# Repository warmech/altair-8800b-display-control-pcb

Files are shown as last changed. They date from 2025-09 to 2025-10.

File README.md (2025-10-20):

# Altair 8800B Display/Control PCB
This is a reproduction of the Altair 8800B Display/Control PCB, with some cleanup and reorganization of trace routing and pad placement. The 8800B’s D/C PCB, much like the original 8800’s front panel PCB, is the primary form of I/O for a stock machine: the LEDs for indicating the data/address/control signals and switches for setting the address and inputting data as well as controlling the CPU are to be found on this PCB. Unlike the original 8800, which drove the LEDs directly off the system bus, the 8800B D/C PCB buffers all signals and uses a 1702 EPROM (or just “PROM” as it would have originally been called) to pass control instructions off to the CPU.

This version of the D/C PCB is not a true 1:1 reproduction (just like the 8800B CPU and Interface cards), but strives to maintain a closely similar layout and trace routing to try to ensure that the hidden “feature” of the Altair remained present: the ability to generate EMI off the D/C board in such a fashion that music can be generated and received via an AM radio at very close proximity.

This design is presently untested and I am awaiting a set to be fabricated. Once I have tested this card in my 8800B, I will update this disclaimer to indicate as much. Until this disclaimer is updated and/or removed, this PCB is to be strictly treated as experimental only. User beware – these project and fabrication files are provided with absolutely zero guarantees.

For the accompanying CPU, Interface, and 1702-to-2716/32 adapter boards, please see the following repositories:

[Altair 8800B CPU Card](https://github.com/warmech/altair-8800b-cpu-card)

[Altair 8800B Interface Card](https://github.com/warmech/altair-8800b-interface-card)

[Altair 8800B 1702-to-2716/2732 Adapter](https://github.com/warmech/altair-8800b-1702-to-2716-eprom-adapter)

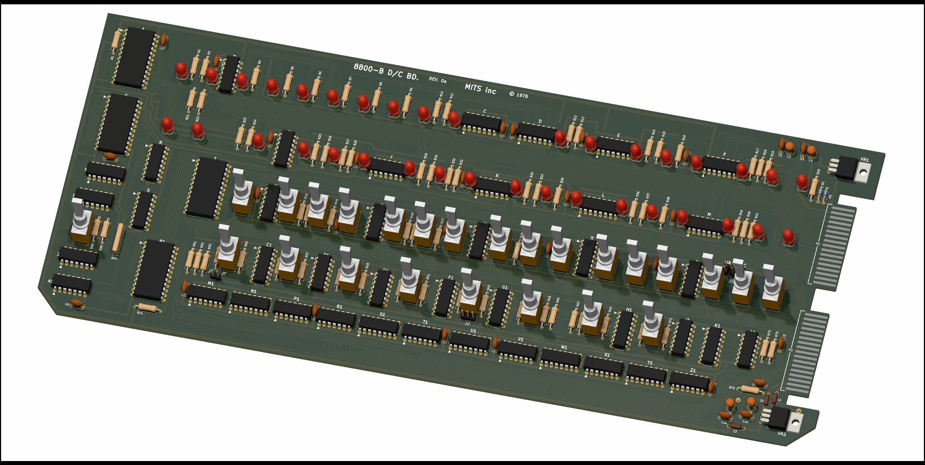
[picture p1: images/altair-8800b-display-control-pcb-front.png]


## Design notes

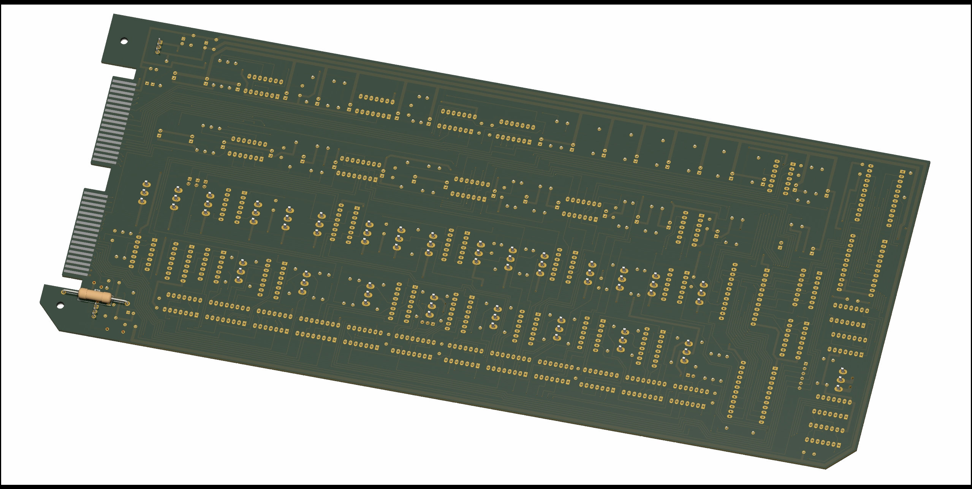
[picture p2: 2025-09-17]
images/altair-8800b-display-control-pcb-rear.png

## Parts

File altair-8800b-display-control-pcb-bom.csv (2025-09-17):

Source:
Date: | 9/16/2025 17:35
Tool: | Eeschema 7.0.11-rc3
Generator:
Component Count: | 232
Collated Components:
Item | Qty | Reference(s) | Value | LibPart | Footprint | Datasheet | DNP | Sim.Device | Sim.Pins
1 | 26 | C1, C3, C10, C11, C12, C13, C14, C15, C16, C17, C18, C19, C20, C21, C22, C23, C24, C25, C26, C27, C28, C29, C30, C31, C32, C33 | 0.1uF / 16V | Device:C | Capacitor_THT_Custom:C_Disc_D7.0mm_W2.3mm_P5.00mm | ~
2 | 4 | C2, C4, C8, C9 | 47uF / 16V | Device:C_Polarized_US | Capacitor_THT:CP_Radial_Tantal_D4.5mm_P2.50mm | ~
3 | 3 | C5, C6, C7 | 0.001uF | Device:C | Capacitor_THT_Custom:C_Disc_D7.0mm_W2.3mm_P5.00mm | ~
4 | 2 | D1, D2 | 1N914 | Diode:1N914 | Diode_THT:D_DO-35_SOD27_P7.62mm_Horizontal | http://www.vishay.com/docs/85622/1n914.pdf |  | D | 1=K 2=A
5 | 1 | J1 | JF_JE | Connector_Generic:Conn_01x02 | Connector_PinHeader_2.54mm:PinHeader_1x02_P2.54mm_Vertical | ~
6 | 1 | JP1 | JA | Jumper:Jumper_2_Open | Connector_PinHeader_2.54mm:PinHeader_1x02_P2.54mm_Vertical | ~
7 | 1 | JP2 | JB | Jumper:Jumper_2_Open | Connector_PinHeader_2.54mm:PinHeader_1x02_P2.54mm_Vertical | ~
8 | 1 | JP3 | JC | Jumper:Jumper_2_Open | Connector_PinHeader_2.54mm:PinHeader_1x02_P2.54mm_Vertical | ~
9 | 1 | JP4 | G_H_J | Jumper:Jumper_3_Bridged12 | Connector_PinHeader_2.54mm:PinHeader_1x03_P2.54mm_Vertical | ~
10 | 3 | L1, L2, L3 | L | Device:L | Inductor_THT:L_Axial_L5.3mm_D2.2mm_P7.62mm_Horizontal_Vishay_IM-1 | ~
11 | 36 | LED1, LED2, LED3, LED4, LED5, LED6, LED7, LED8, LED9, LED10, LED11, LED12, LED13, LED14, LED15, LED16, LED17, LED18, LED19, LED20, LED21, LED22, LED23, LED24, LED25, LED26, LED27, LED28, LED29, LED30, LED31, LED32, LED33, LED34, LED35, LED36 | LED | Device:LED | LED_THT:LED_D5.0mm | ~
12 | 1 | P1 | D/C Card Edge | :Ribbon_Cable_Card_Edge_Connector_34_Pin_1 | Connector_Custom:Altair_8800B_Display_Control_Card_Edge
13 | 1 | P2 | D/C Card Edge | Connector_Custom:Ribbon_Cable_Card_Edge_Connector_34_Pin | Connector_Custom:Altair_8800B_Display_Control_Card_Edge
14 | 34 | R1, R23, R27, R31, R42, R43, R44, R45, R46, R47, R48, R49, R51, R52, R53, R54, R55, R56, R57, R58, R59, R60, R61, R62, R63, R64, R65, R67, R68, R69, R70, R71, R72, R74 | 2.2K | Device:R_US | Resistor_THT:R_Axial_DIN0309_L9.0mm_D3.2mm_P12.70mm_Horizontal | ~
15 | 37 | R2, R3, R4, R5, R6, R7, R8, R9, R10, R11, R12, R13, R14, R15, R16, R17, R18, R19, R21, R22, R24, R25, R26, R28, R29, R30, R32, R33, R34, R35, R36, R37, R38, R39, R40, R41, R73 | 220 | Device:R_US | Resistor_THT:R_Axial_DIN0309_L9.0mm_D3.2mm_P12.70mm_Horizontal | ~
16 | 1 | R20 | 1K | Device:R_US | Resistor_THT:R_Axial_DIN0309_L9.0mm_D3.2mm_P12.70mm_Horizontal | ~
17 | 2 | R50, R75 | 100 | Device:R_US | Resistor_THT:R_Axial_DIN0309_L9.0mm_D3.2mm_P12.70mm_Horizontal | ~
18 | 1 | R66 | 470 | Device:R_US | Resistor_THT:R_Axial_DIN0309_L9.0mm_D3.2mm_P12.70mm_Horizontal | ~
19 | 1 | R76 | 5 Ohm / 4W | Device:R_US | Resistor_THT:R_Axial_DIN0516_L15.5mm_D5.0mm_P30.48mm_Horizontal | ~
20 | 1 | RP1 | 4.7K | Device:R_Network05_Split | Resistor_THT:R_Array_SIP6 | http://www.vishay.com/docs/31509/csc.pdf
21 | 1 | SW1 | A0 | Switch:SW_SPDT | Switch_Custom:Altair_Toggle_Switch | ~
22 | 1 | SW2 | A1 | Switch:SW_SPDT | Switch_Custom:Altair_Toggle_Switch | ~
23 | 1 | SW3 | A2 | Switch:SW_SPDT | Switch_Custom:Altair_Toggle_Switch | ~
24 | 1 | SW4 | A3 | Switch:SW_SPDT | Switch_Custom:Altair_Toggle_Switch | ~
25 | 1 | SW5 | A4 | Switch:SW_SPDT | Switch_Custom:Altair_Toggle_Switch | ~
26 | 1 | SW6 | A5 | Switch:SW_SPDT | Switch_Custom:Altair_Toggle_Switch | ~
27 | 1 | SW7 | A6 | Switch:SW_SPDT | Switch_Custom:Altair_Toggle_Switch | ~
28 | 1 | SW8 | A7 | Switch:SW_SPDT | Switch_Custom:Altair_Toggle_Switch | ~
29 | 1 | SW9 | A8 | Switch:SW_SPDT | Switch_Custom:Altair_Toggle_Switch | ~
30 | 1 | SW10 | A9 | Switch:SW_SPDT | Switch_Custom:Altair_Toggle_Switch | ~
31 | 1 | SW11 | A10 | Switch:SW_SPDT | Switch_Custom:Altair_Toggle_Switch | ~
32 | 1 | SW12 | A11 | Switch:SW_SPDT | Switch_Custom:Altair_Toggle_Switch | ~
33 | 1 | SW13 | A12 | Switch:SW_SPDT | Switch_Custom:Altair_Toggle_Switch | ~
34 | 2 | SW14, SW25 | A13 | Switch:SW_SPDT | Switch_Custom:Altair_Toggle_Switch | ~
35 | 1 | SW15 | A14 | Switch:SW_SPDT | Switch_Custom:Altair_Toggle_Switch | ~
36 | 1 | SW16 | A15 | Switch:SW_SPDT | Switch_Custom:Altair_Toggle_Switch | ~
37 | 1 | SW17 | STOP_RUN | Switch:SW_SPDT_MSM | Switch_Custom:Altair_Toggle_Switch_Momentary | ~
38 | 1 | SW18 | STEP_SLOW | Switch:SW_SPDT_MSM | Switch_Custom:Altair_Toggle_Switch_Momentary | ~
39 | 1 | SW19 | EXAMINE_NEXT | Switch:SW_SPDT_MSM | Switch_Custom:Altair_Toggle_Switch_Momentary | ~
40 | 1 | SW20 | DEPOSIT_NEXT | Switch:SW_SPDT_MSM | Switch_Custom:Altair_Toggle_Switch_Momentary | ~
41 | 1 | SW21 | ACC_DIS_DEP | Switch:SW_SPDT_MSM | Switch_Custom:Altair_Toggle_Switch_Momentary | ~
42 | 1 | SW22 | IN_OUT | Switch:SW_SPDT_MSM | Switch_Custom:Altair_Toggle_Switch_Momentary | ~
43 | 1 | SW23 | RESET_CLR | Switch:SW_SPDT_MSM | Switch_Custom:Altair_Toggle_Switch_Momentary | ~
44 | 1 | SW24 | PROT_UNPROT | Switch:SW_SPDT_MSM | Switch_Custom:Altair_Toggle_Switch_Momentary | ~
45 | 1 | U1 | 8212 (A) | Interface_Custom:8212 | Package_DIP:DIP-24_W15.24mm_LongPads
46 | 1 | U2 | 74LS07 (B) | 74xx:74LS07 | Package_DIP:DIP-14_W7.62mm_LongPads | www.ti.com/lit/ds/symlink/sn74ls07.pdf
47 | 1 | U3 | 74LS04 (C) | 74xx:74LS04 | Package_DIP:DIP-14_W7.62mm_LongPads | http://www.ti.com/lit/gpn/sn74LS04
48 | 1 | U4 | 74LS07 (D) | 74xx:74LS07 | Package_DIP:DIP-14_W7.62mm_LongPads | www.ti.com/lit/ds/symlink/sn74ls07.pdf
49 | 1 | U5 | 74LS07 (E) | 74xx:74LS07 | Package_DIP:DIP-14_W7.62mm_LongPads | www.ti.com/lit/ds/symlink/sn74ls07.pdf
50 | 1 | U6 | 74LS07 (F) | 74xx:74LS07 | Package_DIP:DIP-14_W7.62mm_LongPads | www.ti.com/lit/ds/symlink/sn74ls07.pdf
51 | 1 | U8 | 74LS07 (H) | 74xx:74LS07 | Package_DIP:DIP-14_W7.62mm_LongPads | www.ti.com/lit/ds/symlink/sn74ls07.pdf
52 | 1 | U9 | 74LS10 (J) | 74xx:74LS10 | Package_DIP:DIP-14_W7.62mm_LongPads | http://www.ti.com/lit/gpn/sn74LS10
53 | 1 | U10 | 74LS07 (K) | 74xx:74LS07 | Package_DIP:DIP-14_W7.62mm_LongPads | www.ti.com/lit/ds/symlink/sn74ls07.pdf
54 | 1 | U11 | 4040 (L) | 4xxx:4040 | Package_DIP:DIP-16_W7.62mm_LongPads | http://www.intersil.com/content/dam/Intersil/documents/cd40/cd4020bms-24bms-40bms.pdf
55 | 1 | U12 | 74LS07 (M) | 74xx:74LS07 | Package_DIP:DIP-14_W7.62mm_LongPads | www.ti.com/lit/ds/symlink/sn74ls07.pdf
56 | 1 | U13 | 74LS30 (N) | :74LS30_1 | Package_DIP:DIP-14_W7.62mm_LongPads | http://www.ti.com/lit/gpn/sn74LS30
57 | 1 | U14 | 7493 (P) | 74xx_Custom:7493 | Package_DIP:DIP-14_W7.62mm_LongPads
58 | 1 | U15 | 74LS368 (R) | 74xx:74LS368 | Package_DIP:DIP-16_W7.62mm_LongPads | http://www.ti.com/lit/gpn/sn74LS368
59 | 1 | U16 | 74LS368 (S) | 74xx:74LS368 | Package_DIP:DIP-16_W7.62mm_LongPads | http://www.ti.com/lit/gpn/sn74LS368
60 | 1 | U17 | 8212 (T) | Interface_Custom:8212 | Package_DIP:DIP-24_W15.24mm_LongPads
61 | 1 | U18 | 74LS05 (U) | 74xx:74LS05 | Package_DIP:DIP-14_W7.62mm_LongPads | http://www.ti.com/lit/gpn/sn74LS05
62 | 1 | U19 | 74LS10 (V) | 74xx:74LS10 | Package_DIP:DIP-14_W7.62mm_LongPads | http://www.ti.com/lit/gpn/sn74LS10
63 | 1 | U20 | 74LS05 (W) | 74xx:74LS05 | Package_DIP:DIP-14_W7.62mm_LongPads | http://www.ti.com/lit/gpn/sn74LS05
64 | 1 | U21 | 4040 (X) | 4xxx:4040 | Package_DIP:DIP-16_W7.62mm_LongPads | http://www.intersil.com/content/dam/Intersil/documents/cd40/cd4020bms-24bms-40bms.pdf
65 | 1 | U22 | 74LS05 (Y) | 74xx:74LS05 | Package_DIP:DIP-14_W7.62mm_LongPads | http://www.ti.com/lit/gpn/sn74LS05
66 | 1 | U23 | 74LS00 (Z) | 74xx:74LS00 | Package_DIP:DIP-14_W7.62mm_LongPads | http://www.ti.com/lit/gpn/sn74ls00
67 | 1 | U24 | 74LS14 (A1) | 74xx:74LS14 | Package_DIP:DIP-14_W7.62mm_LongPads | http://www.ti.com/lit/gpn/sn74LS14
68 | 1 | U25 | 8212 (B1) | Interface_Custom:8212 | Package_DIP:DIP-24_W15.24mm_LongPads
69 | 1 | U26 | 74LS175 (C1) | :74LS175_2 | Package_DIP:DIP-16_W7.62mm_LongPads | http://www.ti.com/lit/gpn/sn74LS175
70 | 1 | U27 | 74LS10 (D1) | 74xx:74LS10 | Package_DIP:DIP-14_W7.62mm_LongPads | http://www.ti.com/lit/gpn/sn74LS10
71 | 1 | U28 | 74LS04 (E1) | 74xx:74LS04 | Package_DIP:DIP-14_W7.62mm_LongPads | http://www.ti.com/lit/gpn/sn74LS04
72 | 1 | U29 | 74LS175 (F1) | :74LS175_3 | Package_DIP:DIP-16_W7.62mm_LongPads | http://www.ti.com/lit/gpn/sn74LS175
73 | 1 | U30 | 74LS175 (G1) | :74LS175_5 | Package_DIP:DIP-16_W7.62mm_LongPads | http://www.ti.com/lit/gpn/sn74LS175
74 | 1 | U31 | 74LS175 (H1) | :74LS175_4 | Package_DIP:DIP-16_W7.62mm_LongPads | http://www.ti.com/lit/gpn/sn74LS175
75 | 1 | U32 | 74LS04 (J1) | 74xx:74LS04 | Package_DIP:DIP-14_W7.62mm_LongPads | http://www.ti.com/lit/gpn/sn74LS04
76 | 1 | U33 | 74LS367 (K1) | 74xx:74LS367 | Package_DIP:DIP-16_W7.62mm_LongPads | http://www.ti.com/lit/gpn/sn74LS367
77 | 1 | U34 | 74LS74 (L1) | 74xx:74LS74 | Package_DIP:DIP-14_W7.62mm_LongPads | 74xx/74hc_hct74.pdf
78 | 1 | U35 | 74LS74 (M1) | 74xx:74LS74 | Package_DIP:DIP-14_W7.62mm_LongPads | 74xx/74hc_hct74.pdf
79 | 1 | U36 | 74LS175 (N1) | :74LS175_1 | Package_DIP:DIP-16_W7.62mm_LongPads | http://www.ti.com/lit/gpn/sn74LS175
80 | 1 | U37 | 74LS00 (P1) | 74xx:74LS00 | Package_DIP:DIP-14_W7.62mm_LongPads | http://www.ti.com/lit/gpn/sn74ls00
81 | 1 | U38 | 74LS04 (R1) | 74xx:74LS04 | Package_DIP:DIP-14_W7.62mm_LongPads | http://www.ti.com/lit/gpn/sn74LS04
82 | 1 | U39 | 4009 (S1) | 4xxx:4009 | Package_DIP:DIP-16_W7.62mm_LongPads | http://www.sycelectronica.com.ar/semiconductores/CD4009.pdf
83 | 1 | U40 | 74LS10 (T1) | 74xx:74LS10 | Package_DIP:DIP-14_W7.62mm_LongPads | http://www.ti.com/lit/gpn/sn74LS10
84 | 1 | U41 | 74LS175 (U1) | :74LS175_6 | Package_DIP:DIP-16_W7.62mm_LongPads | http://www.ti.com/lit/gpn/sn74LS175
85 | 1 | U42 | 74LS05 (V1) | 74xx:74LS05 | Package_DIP:DIP-14_W7.62mm_LongPads | http://www.ti.com/lit/gpn/sn74LS05
86 | 1 | U43 | 74LS175 (W1) | 74xx:74LS175 | Package_DIP:DIP-16_W7.62mm_LongPads | http://www.ti.com/lit/gpn/sn74LS175
87 | 1 | U44 | 74LS30 (X1) | 74xx:74LS30 | Package_DIP:DIP-14_W7.62mm_LongPads | http://www.ti.com/lit/gpn/sn74LS30
88 | 1 | U45 | 74LS175 (Y1) | :74LS175_7 | Package_DIP:DIP-16_W7.62mm_LongPads | http://www.ti.com/lit/gpn/sn74LS175
89 | 1 | U46 | 74LS05 (Z1) | 74xx:74LS05 | Package_DIP:DIP-14_W7.62mm_LongPads | http://www.ti.com/lit/gpn/sn74LS05
90 | 1 | UA7 | 1702 (G) | Memory_EPROM_Custom:1702 | Package_DIP:DIP-24_W15.24mm_LongPads
91 | 1 | UB7 | 2732 (G) | Memory_EPROM_Custom:2732 | Package_DIP:DIP-24_W15.24mm
92 | 1 | VR1 | LM320T | Regulator_Linear_Custom:LM320T | Package_TO_SOT_THT:TO-220-3_Horizontal_TabDown | https://www.ti.com/lit/ds/symlink/lm120.pdf?ts=1756100270281
93 | 1 | VR2 | L7805 | Regulator_Linear:L7805 | Package_TO_SOT_THT:TO-220-3_Horizontal_TabDown | http://www.st.com/content/ccc/resource/technical/document/datasheet/41/4f/b3/b0/12/d4/47/88/CD00000444.pdf/files/CD00000444.pdf/jcr:content/translations/en.CD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

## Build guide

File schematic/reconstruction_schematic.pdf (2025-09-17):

# Altair 8800b-r Computer

# Altair 8800b - Reconstruction

# Schematic

## Contents

Section | Assemblies | Page
Title & Contents (this page) | - | N1
Notes | - | N2
Front Panel - Power & Clock | FP & FN | FP1
Front Panel - Display LEDs | FP & FN | FP2
Front Panel - Function Switches & Run Control | FP & FN | FP3
Front Panel - Sequencer | FP & FN | FP4
Front Panel - Interface Recon. Layout & ICs | FN | FP5

# Altair 8800b-r Computer

## Section: Title & Contents

Page: N1 | Rendition: Mar 8, 2024

## NOTES

## - IC locations are identified by a label of the form: U<board><alpha>

## <board> = two characters FP = Front Panel FN = Front Panel Interface

## - The symbol represents a connector pin. The solid black end is the male

side, the white-filled end is the female side.

## Connector pins are identified by a label of the form: N <connector> . <pin>

## - A small black marker on the upper half of a gate symbol indicates an open-

collector output.

## - Based on the MITS schematic with alterations for reconstructed interface

board.

- 2021 Jun: This drawing / bhilpert.

# Altair 8800b-r Computer

## Section: Notes

Page: N2 | Rendition: Mar 8, 2024

JUMPERS

FP.A-D: | Slow is 8 / Sec | [8800b.pdf.5-26]
FP.B-D: | Slow is 2 / Sec
FP.C-D: | Slow is 1 / 2Sec
FP.E-F | closed: SS/Slow executes an instruction
open: | SS/Slow executes a machine cycle
FP.G-H: | Reset is always active
FP.G-J: | Reset not active when running
FN.A-B | closed: Data LEDs show IO input data | [8800b.pdf.3-89]
open: | Data LEDs do not show IO input data
FN.C-D | closed: Data LEDs show IO output data
open: | Data LEDs do not show IO output data
FN.E-F | closed: Data LEDs show only IO output data addressed to LEDs (port 377)
open: | Data LEDs show all IO output data
FNJX | closed: When running, Data LEDs show last state prior to running,
| or IO data per jumpers FN.A::F.
open: | When running, Data LEDs simply follow S100 DO lines.
FNJY.1-2 | Ready from the front panel drives S100.xRDY.
FNJY.2-3 | Ready from the front panel drives S100.pRDY.

Alterations to avoid peculiarities of 8800b CPU board, allowing operation with the 8800 CPU board.

Implementation differences of reconstructed front panel interface board from original board (function remains the same).

## RATIONAL

This is a schematic for a reconstruction of the Altair 8800b front panel interface board, hereafter referred to as the RIB. The RIB differs from the 8800b interface board in gate organisation and physical layout. Also, several changes have been made to allow use of CPU boards compatible with the original Altair, rather than

## requiring the CPU board unique to the 8800b:

## STSTB

The 8800b CPU board provides a STSTB~ (S100.56) signal to the front panel. This is used by the front panel to prepare the RDY signal.

The 8800 CPU board does not generate STSTB.

The RIB uses Ø2~ in substitute for STSTB. This ‘should’ be Ø1 but an attempt to use Ø1 did not provide enough time till Ø2 for the propagation delay of the long string of gates generating RDY.

## FRDY

The original 8800 uses pRDY (S100.72) to start/stop the CPU for front panel operations. pRDY is a shared assert-LOW signal open for use by other boards. The Altair 8800 front panel however, rather poorly, uses a totem-pole driver for pRDY rather than an OC driver.

The 8800b uses a private signal for CPU start/stop: FRDY (S100.58).

The RIB reverts to the use of the shared pRDY, but uses a tri-state driver wired for OC operation for the line. The front panel board is altered to remove an inverter to reduce the gate propagation delay. **Due to the STSTB alteration, the logic has only from +edge of Ø1 till the +edge of Ø2 to produce pRDY.**

## DIG1

The original 8800 uses 3 signals across the S100 bus from th e front panel to the CPU to inhibit data-input from the bus during front panel operations: RUN, SS & SSWI~ (S100.71,21,53).

The 8800b uses one signal to this end: DIG1~ (S100.57).

The RIB reroutes DIG1~ to SSWI~.

SS

The Single-Step signal to the 8800 CPU board to permit enabling of the S100 data-input onto the CPU data-bus is not needed. SS (S100.21) sits HIGH by default, permitting said enabling by pDBIN or pHLDA. SSWI~ from the RIB disables S100 data-input whenever the front panel needs to feed data to the CPU (via the CP connector), for sense-switch input or for force-feeding the CPU instructions.

- Note: The 8800b CPU board will not function with the RIB due as presented here, due to the removal of the signals specific to the 8800b.
- Note: The 8800b interface board will not function in a machine modified for the RIB due to the alteration of the RDY output on the front panel board.

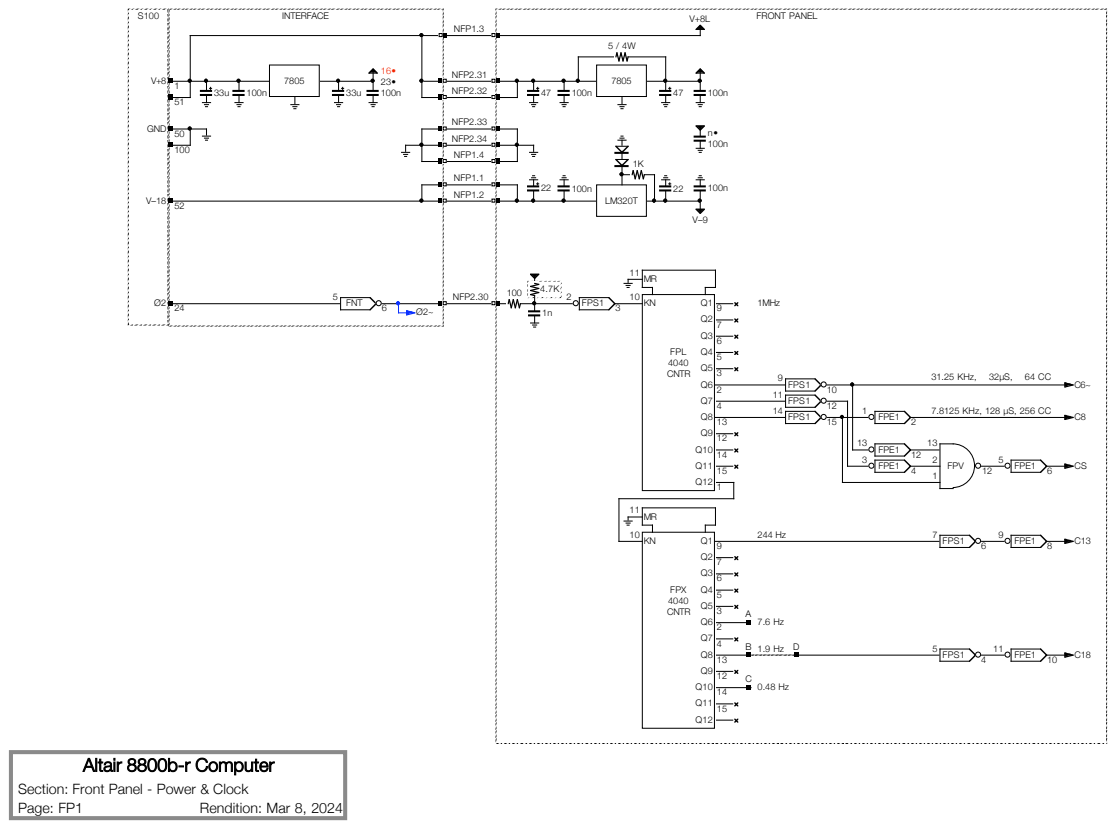
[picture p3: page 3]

NFP2.32

50 GND | NFP2.33

NFP2.34

Section: Front Panel - Power & Clock

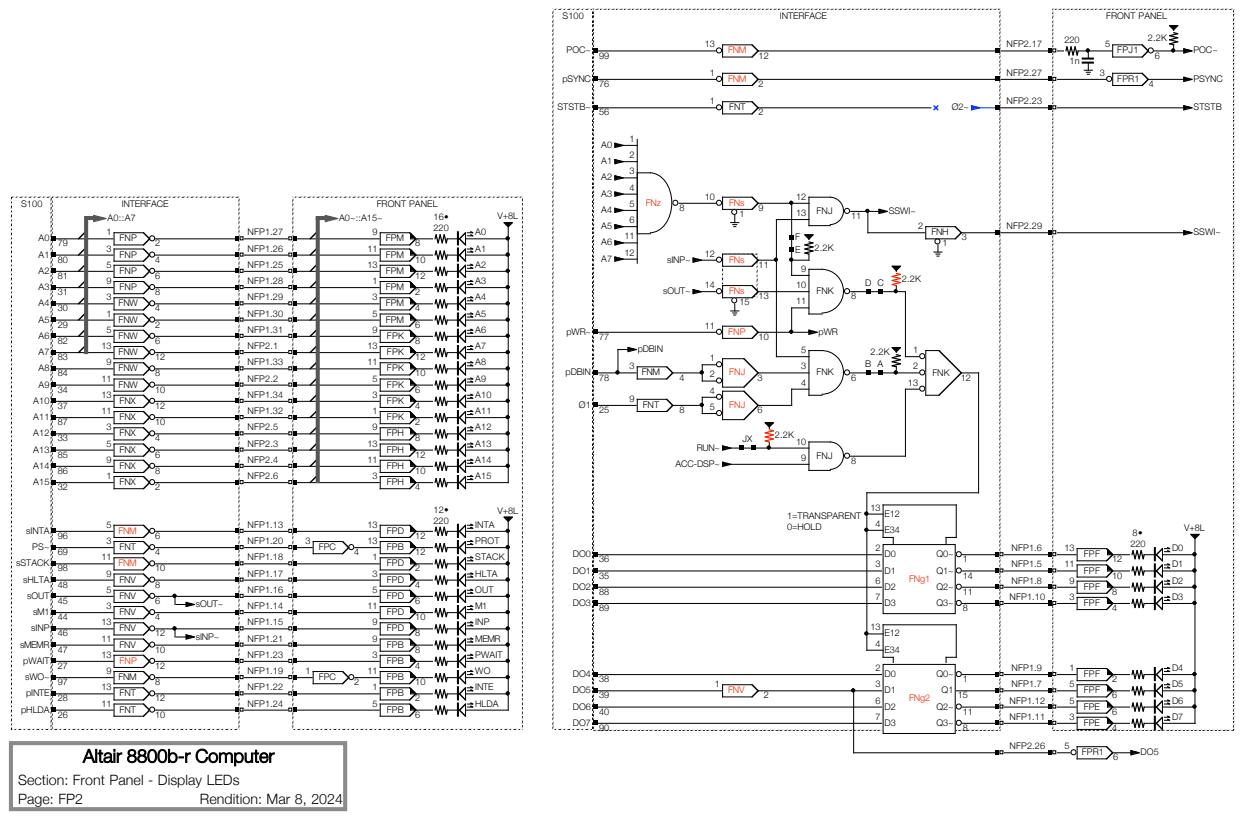
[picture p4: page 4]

36 | 1 3 D1 Q1~ | NFP1.5 | 11 | | | D1
35 | 14 6 D2 FNg1 Q2~ | NFP1.8 | 9 | | | D2
88 | 11 7 D3 Q3~ | NFP1.10 | 3 | | | D3

38 1 | NFP1.7 | 5 | | | D5

NFP1.9

FNg2 15 6 D2 Q2~ | | 5 | | | D6

40 | 11 7 D3 Q3~ | NFP1.11 | 3 | | | D7
90 | 8 | | | 4

Section: Front Panel - Display LEDs

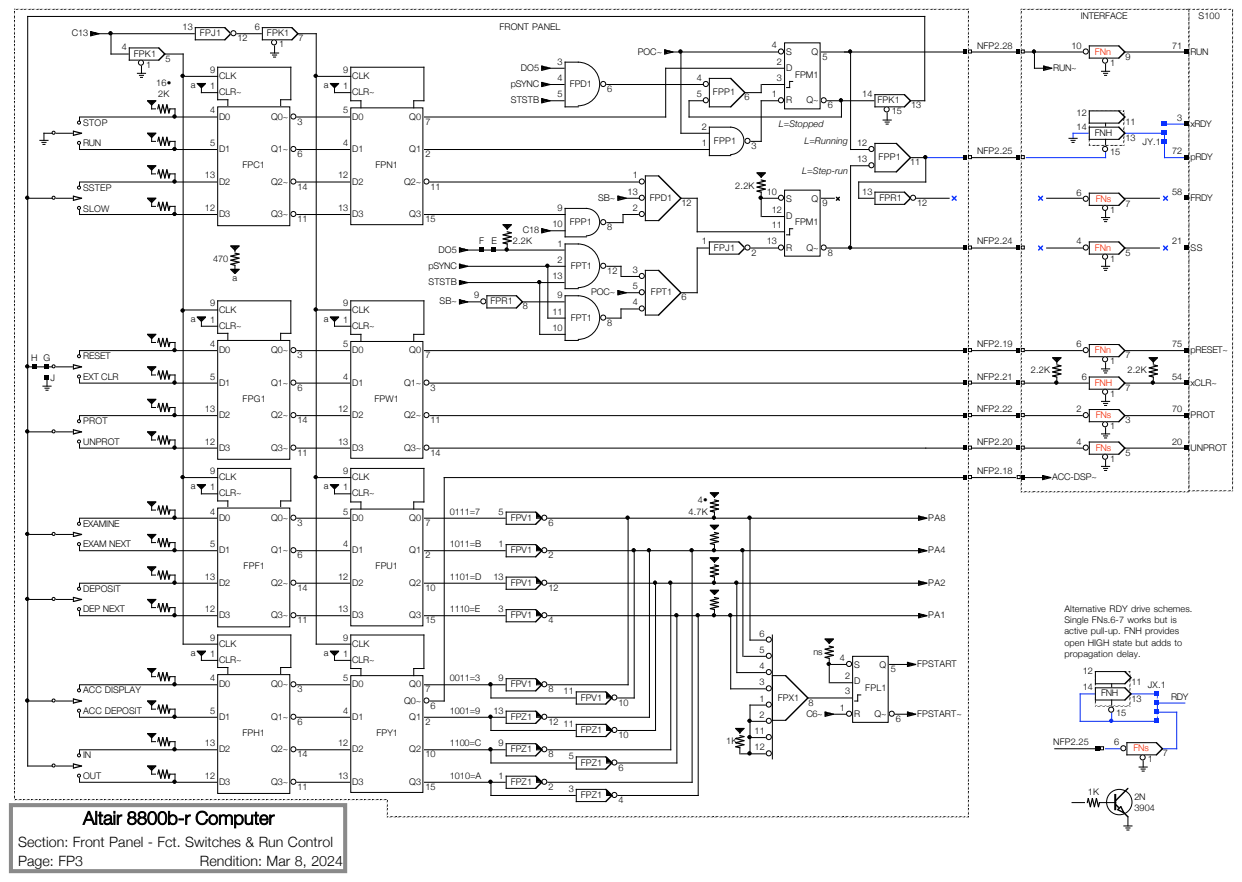
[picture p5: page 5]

Alternative RDY drive schemes.
Single FNs.6-7 works but is
active pull-up. FNH provides
open HIGH state but adds to
propagation delay.

Section: Front Panel - Fct. Switches & Run Control

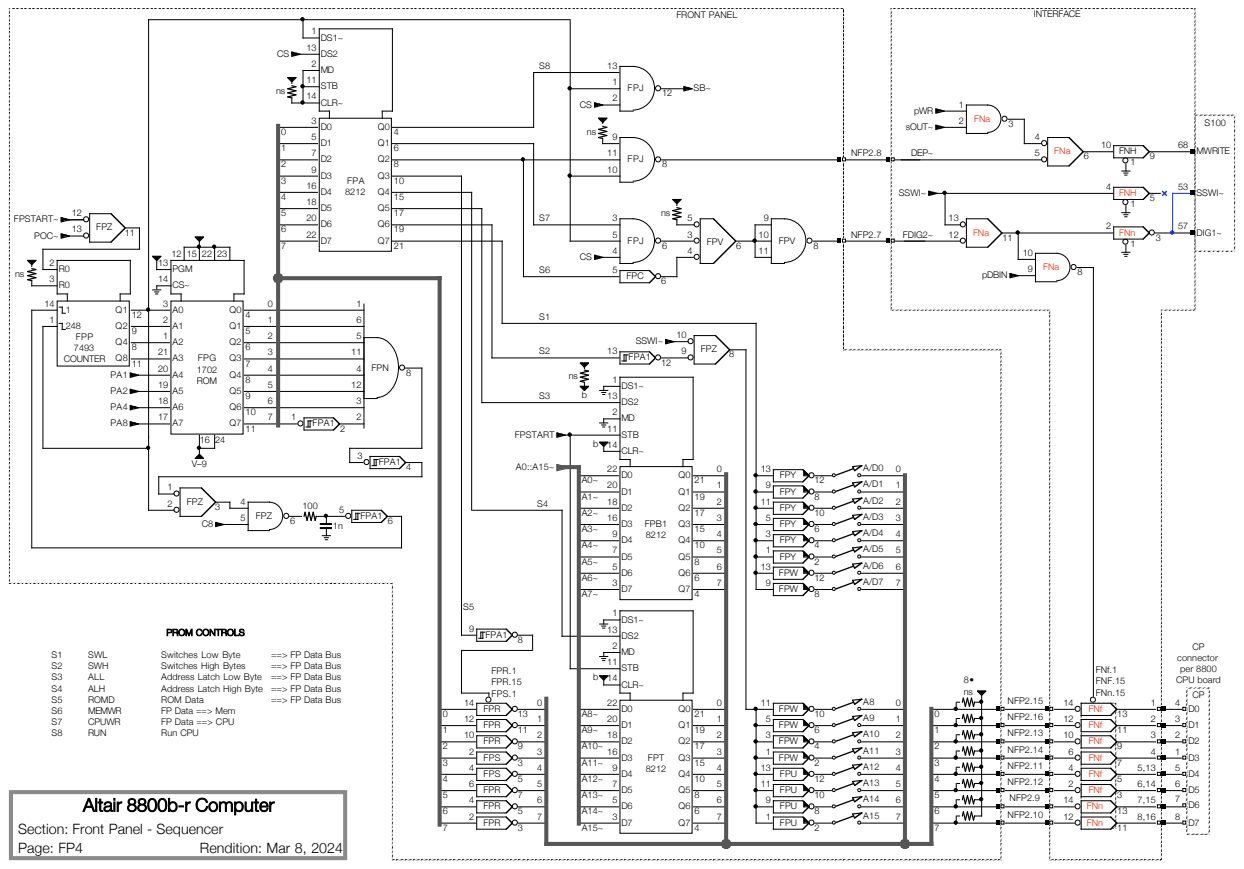
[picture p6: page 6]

4 15 18 D5 Q5
5 17 20 D6 Q6

9 18 A6 Q6 6 | 3
10 17 A7 Q7 7

Section: Front Panel - Sequencer

P1
V–18 | 1 | 2 | V–18

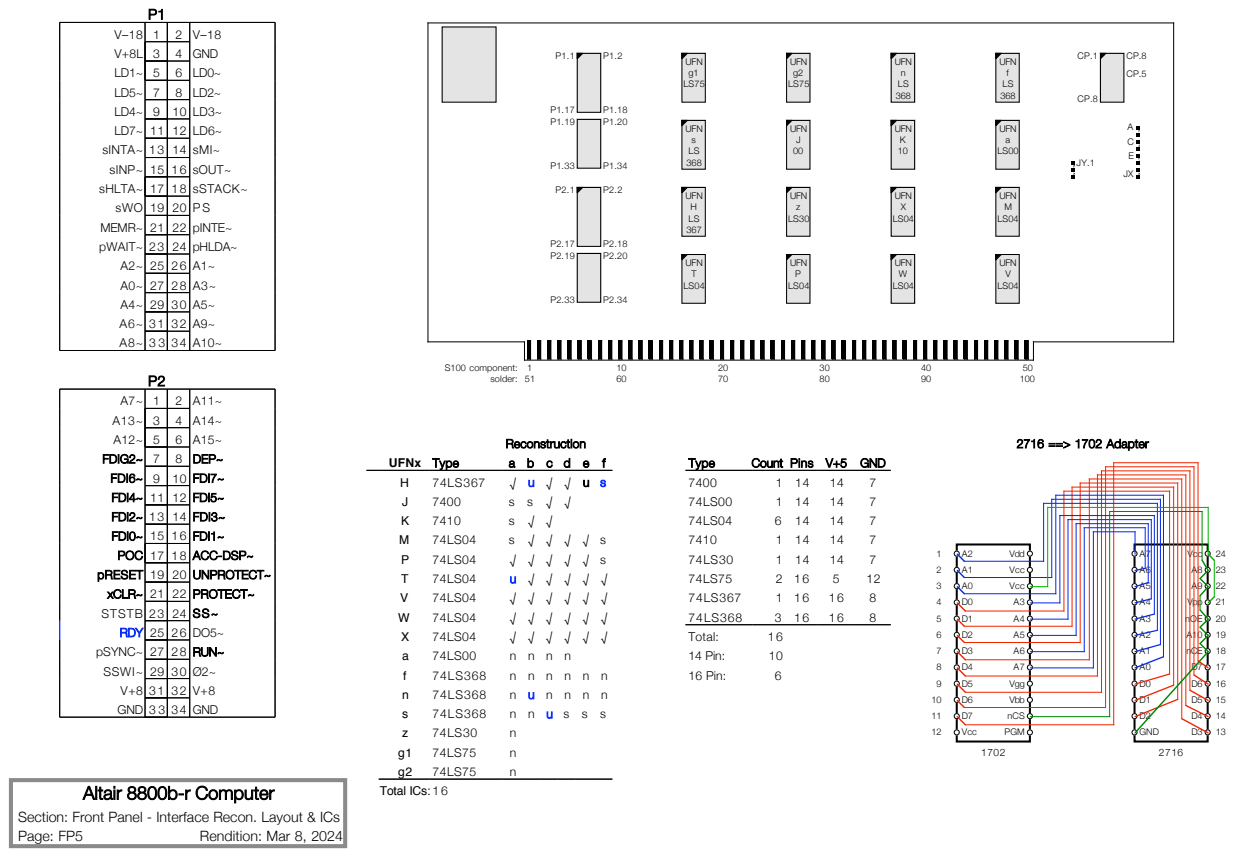
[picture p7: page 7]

Section: Front Panel - Interface Recon. Layout & ICs

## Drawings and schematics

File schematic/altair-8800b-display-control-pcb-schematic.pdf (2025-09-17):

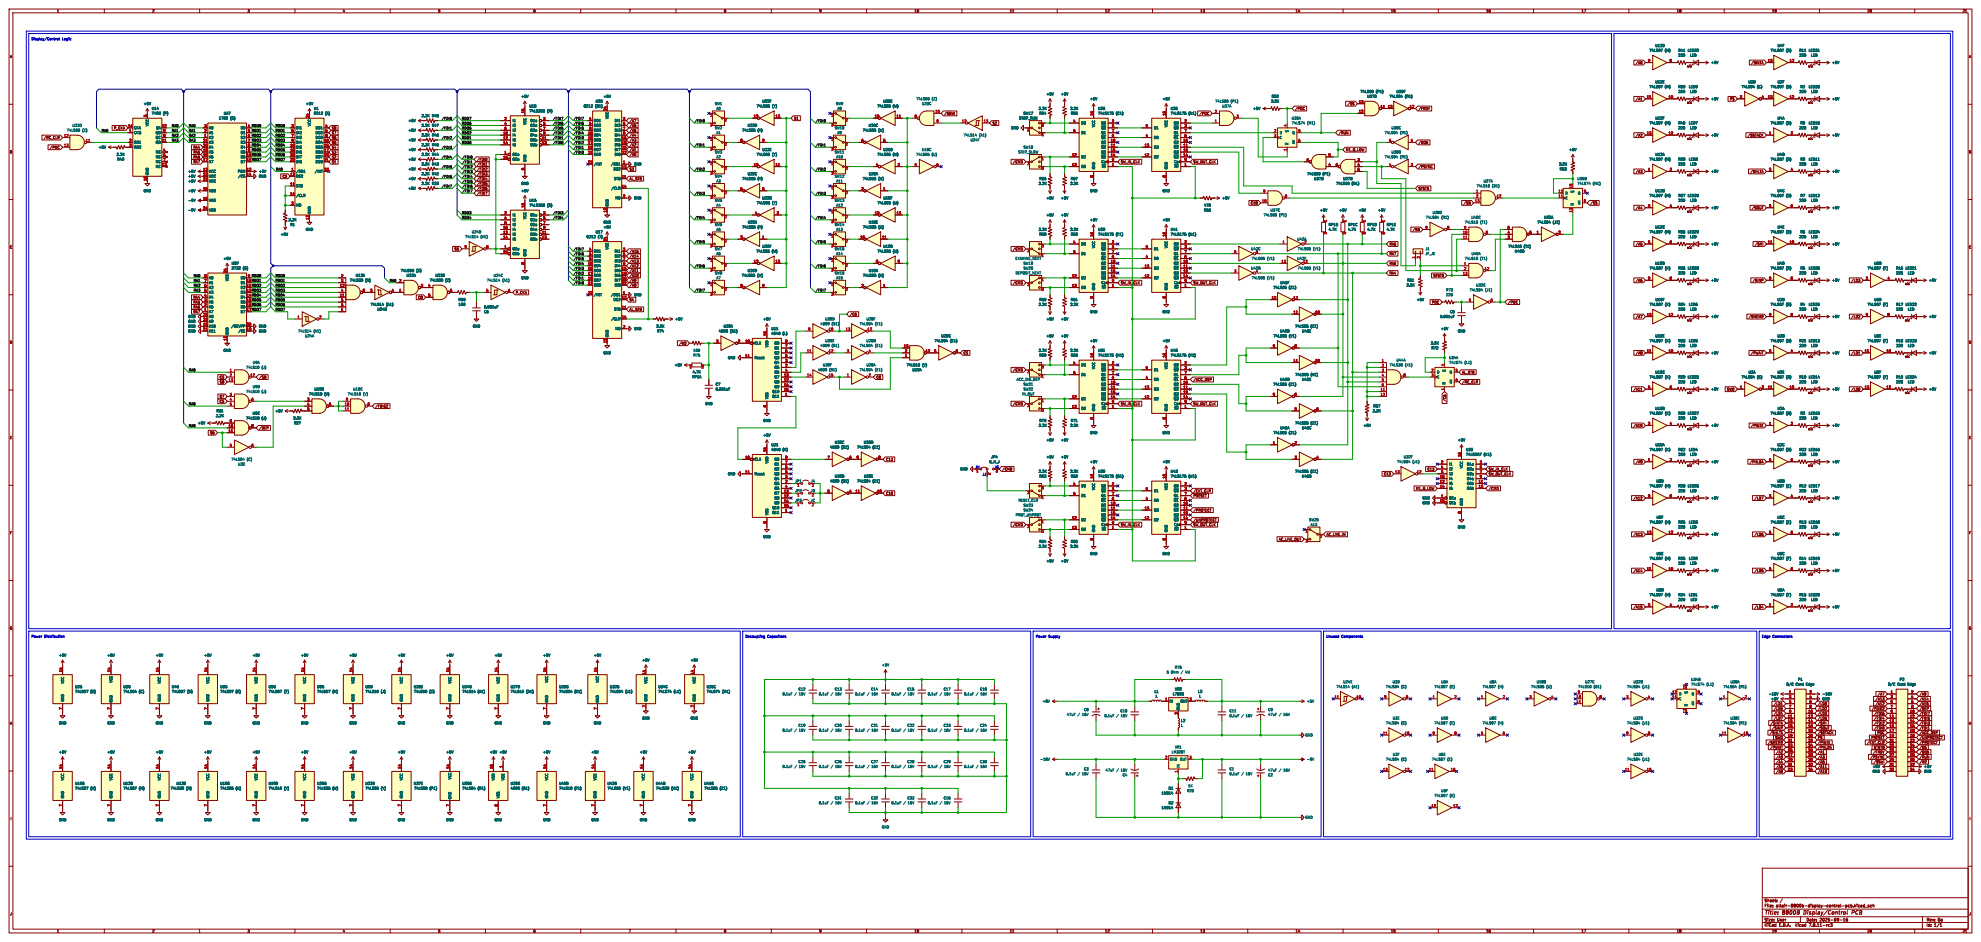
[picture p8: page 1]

GND GND

File: altair-8800b-display-control-pcb.kicad_sch Sheet: /

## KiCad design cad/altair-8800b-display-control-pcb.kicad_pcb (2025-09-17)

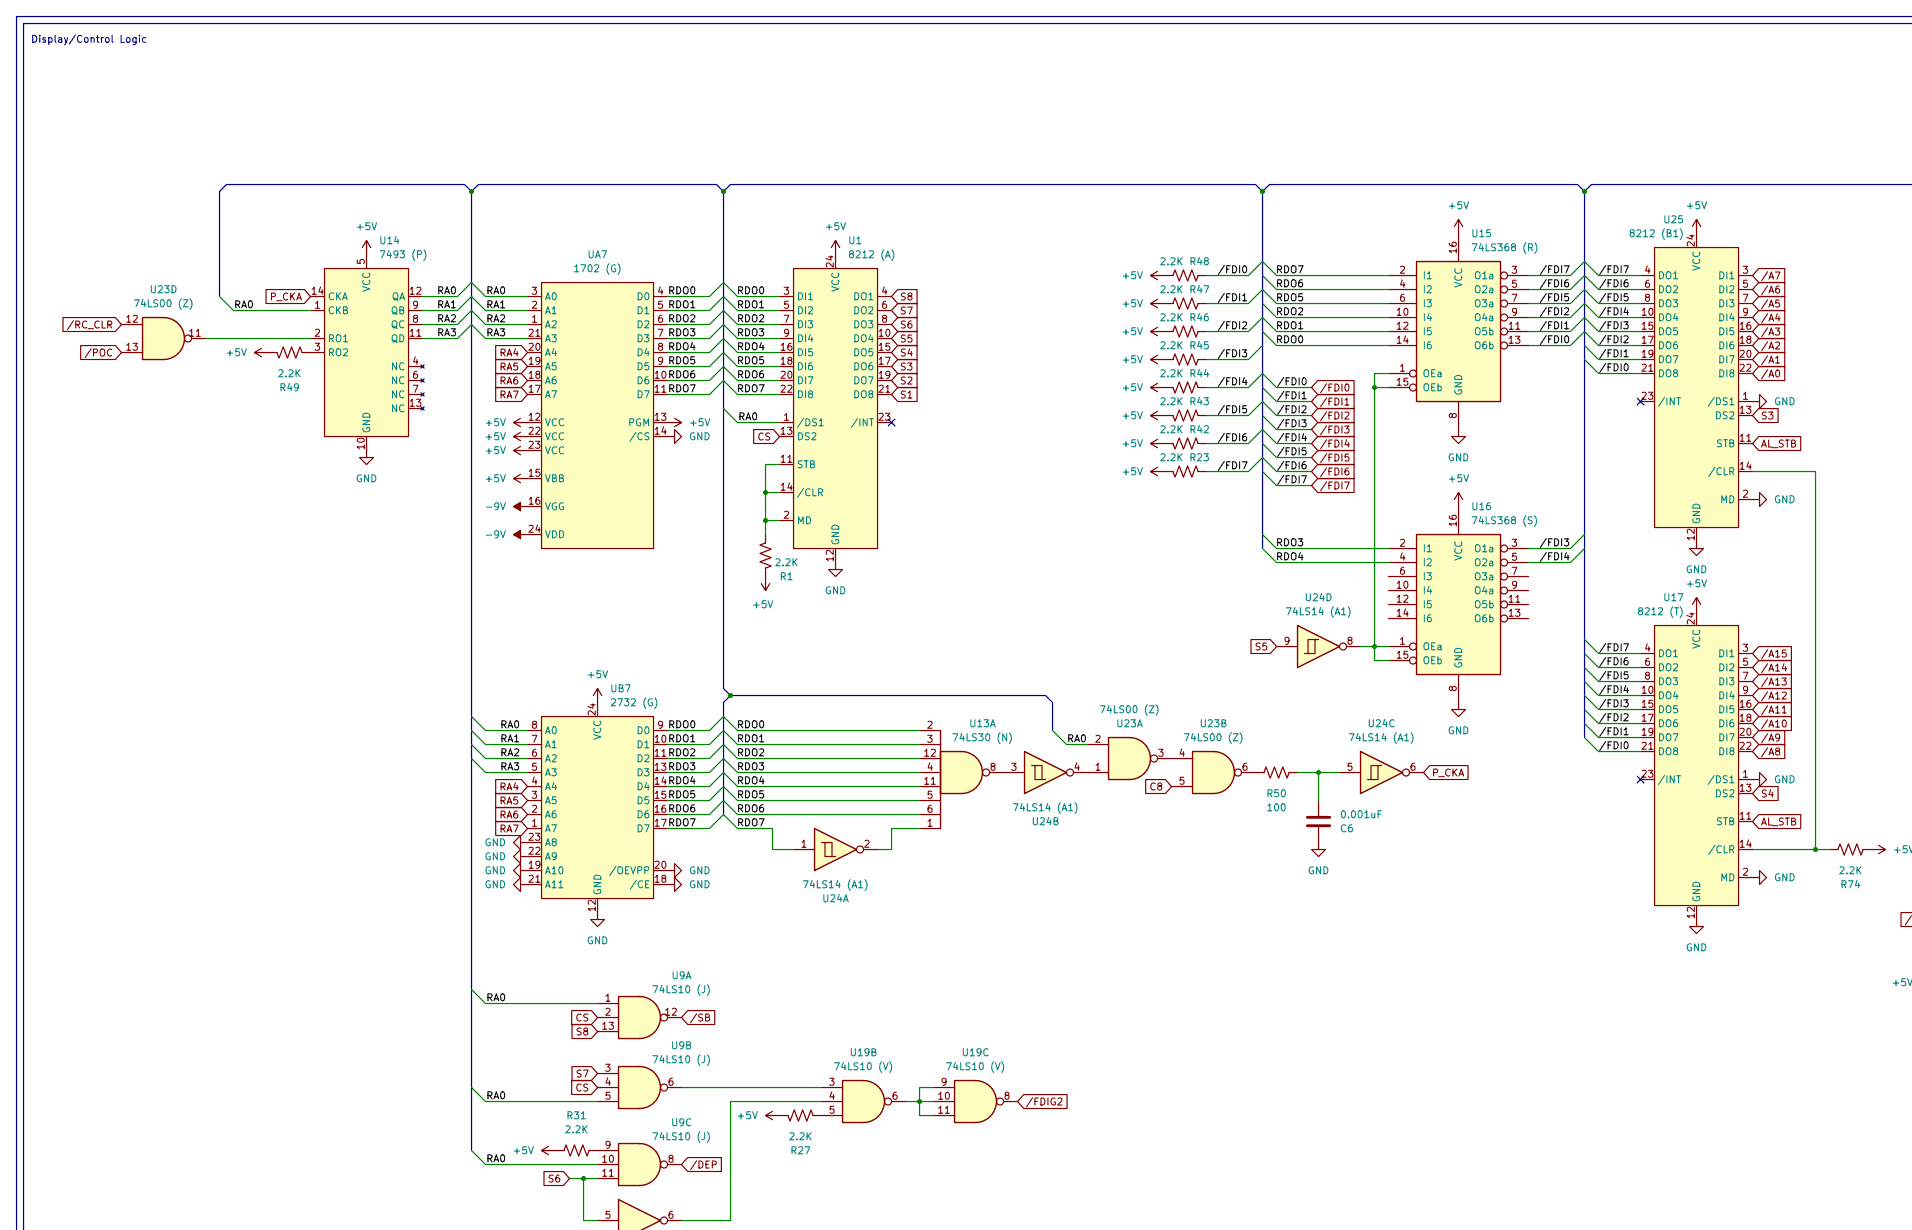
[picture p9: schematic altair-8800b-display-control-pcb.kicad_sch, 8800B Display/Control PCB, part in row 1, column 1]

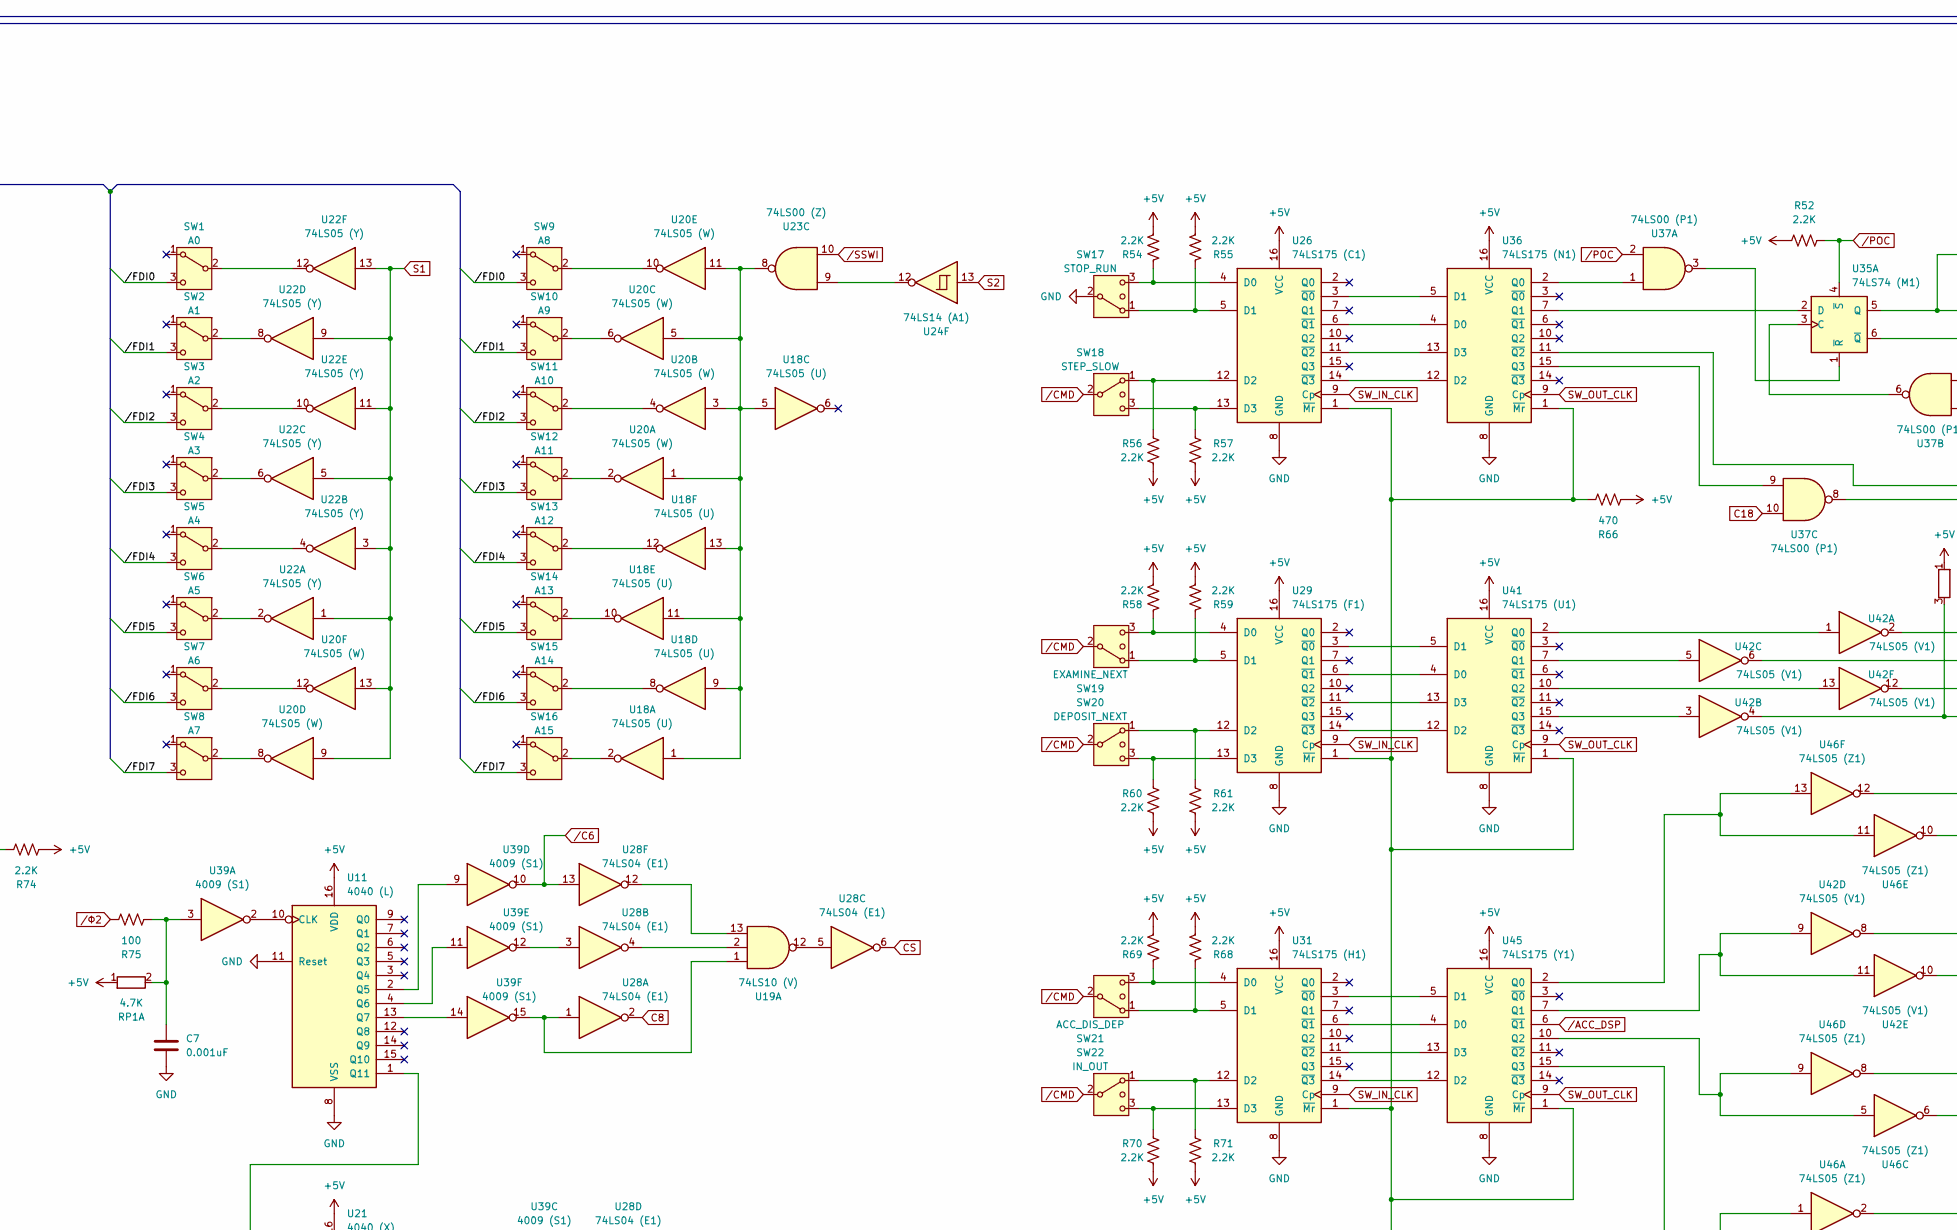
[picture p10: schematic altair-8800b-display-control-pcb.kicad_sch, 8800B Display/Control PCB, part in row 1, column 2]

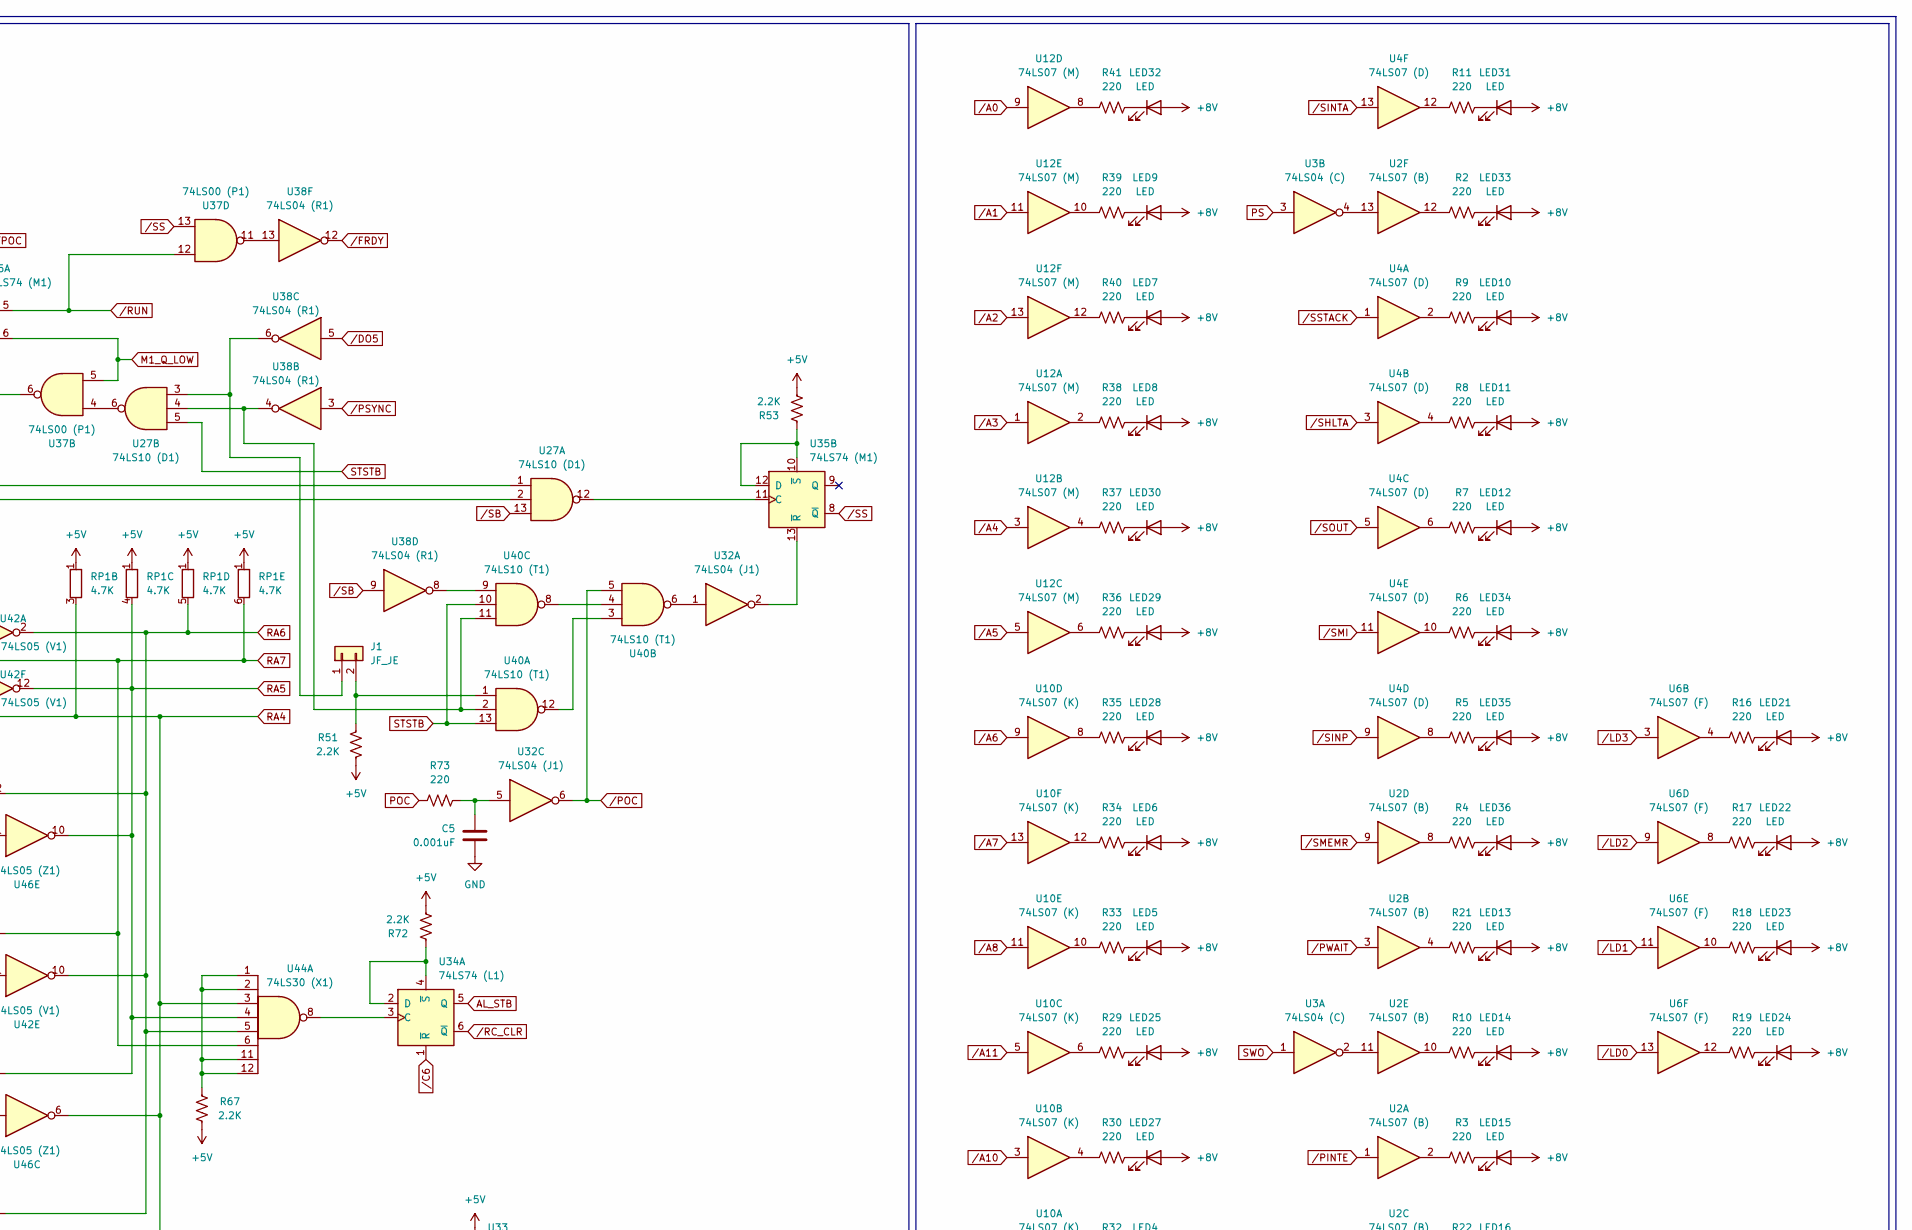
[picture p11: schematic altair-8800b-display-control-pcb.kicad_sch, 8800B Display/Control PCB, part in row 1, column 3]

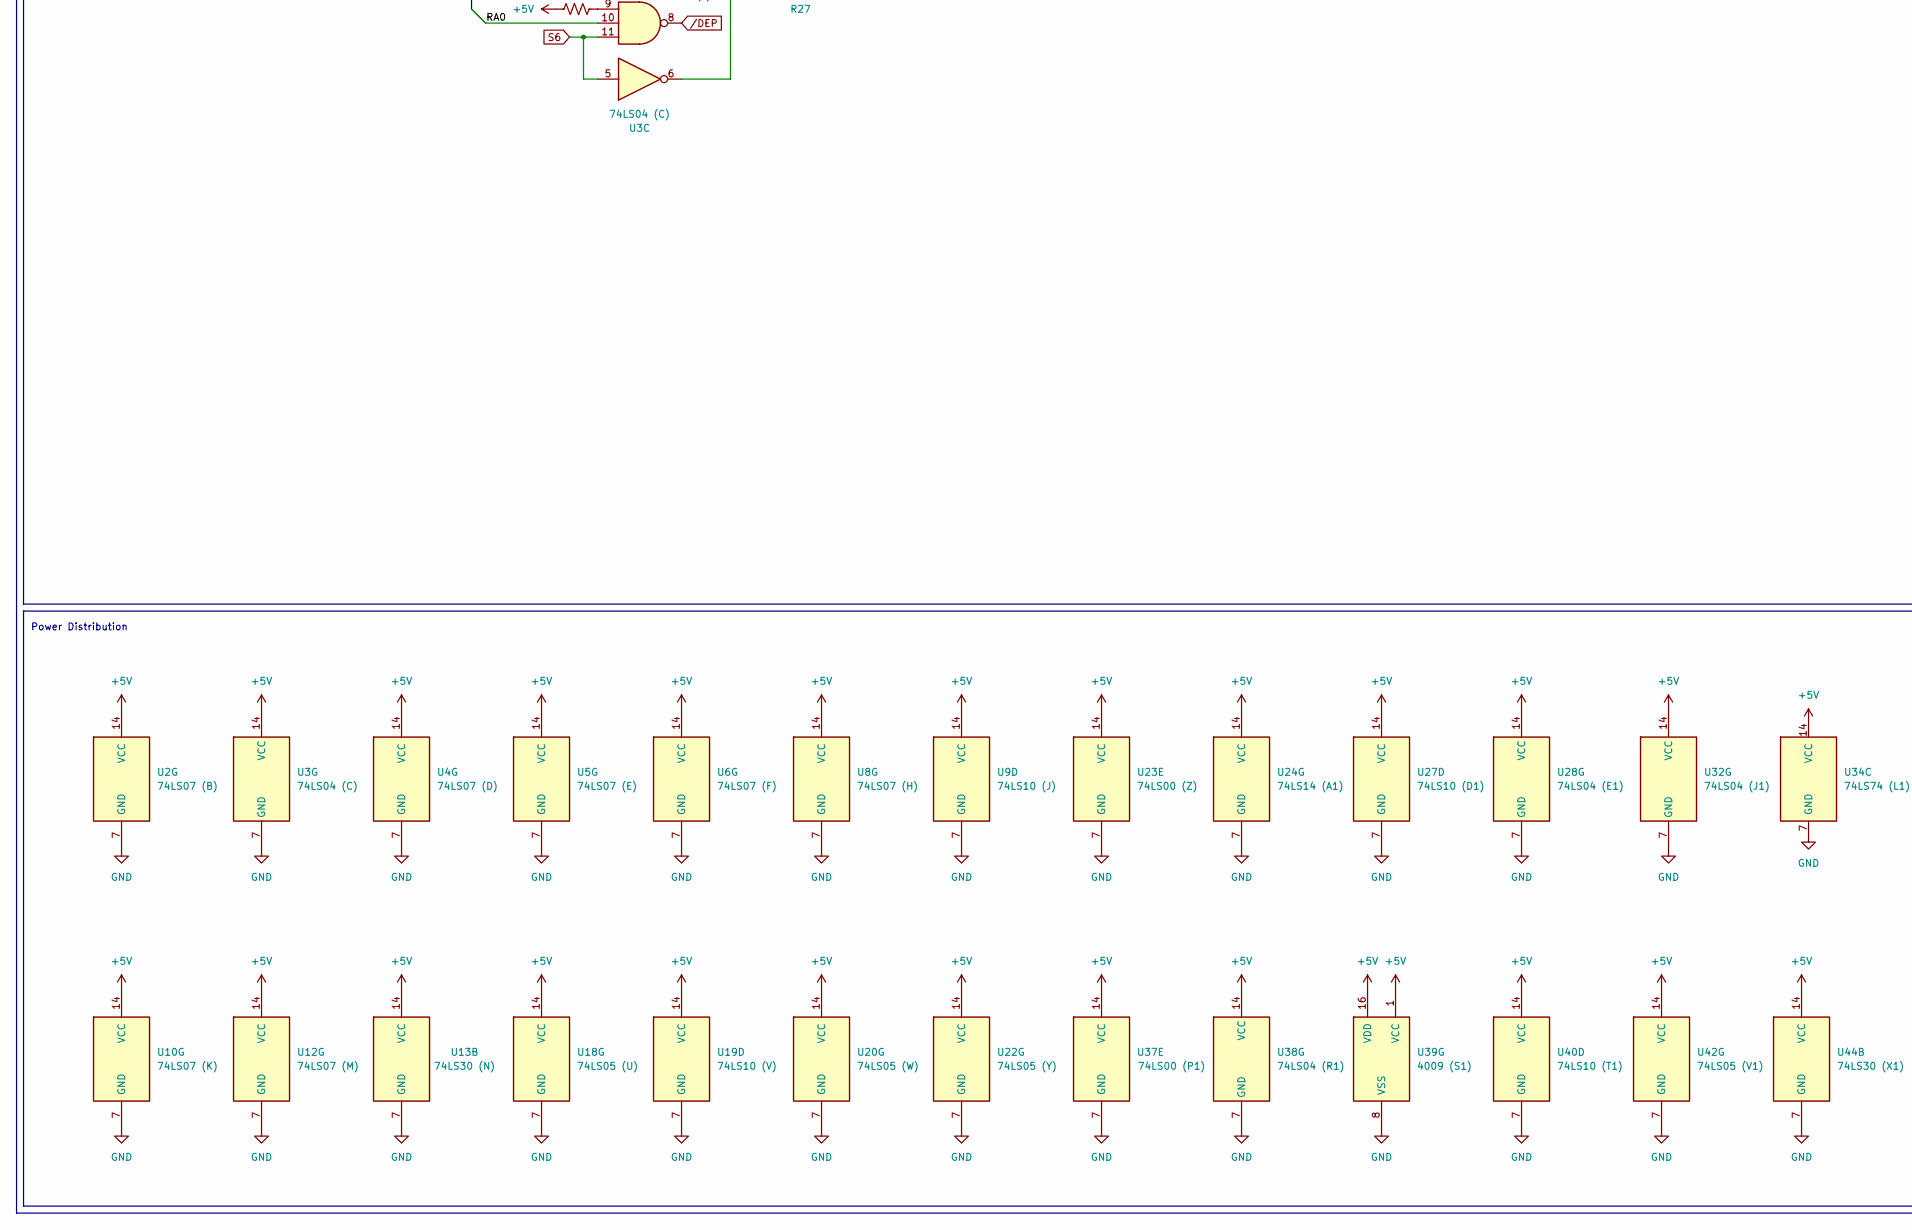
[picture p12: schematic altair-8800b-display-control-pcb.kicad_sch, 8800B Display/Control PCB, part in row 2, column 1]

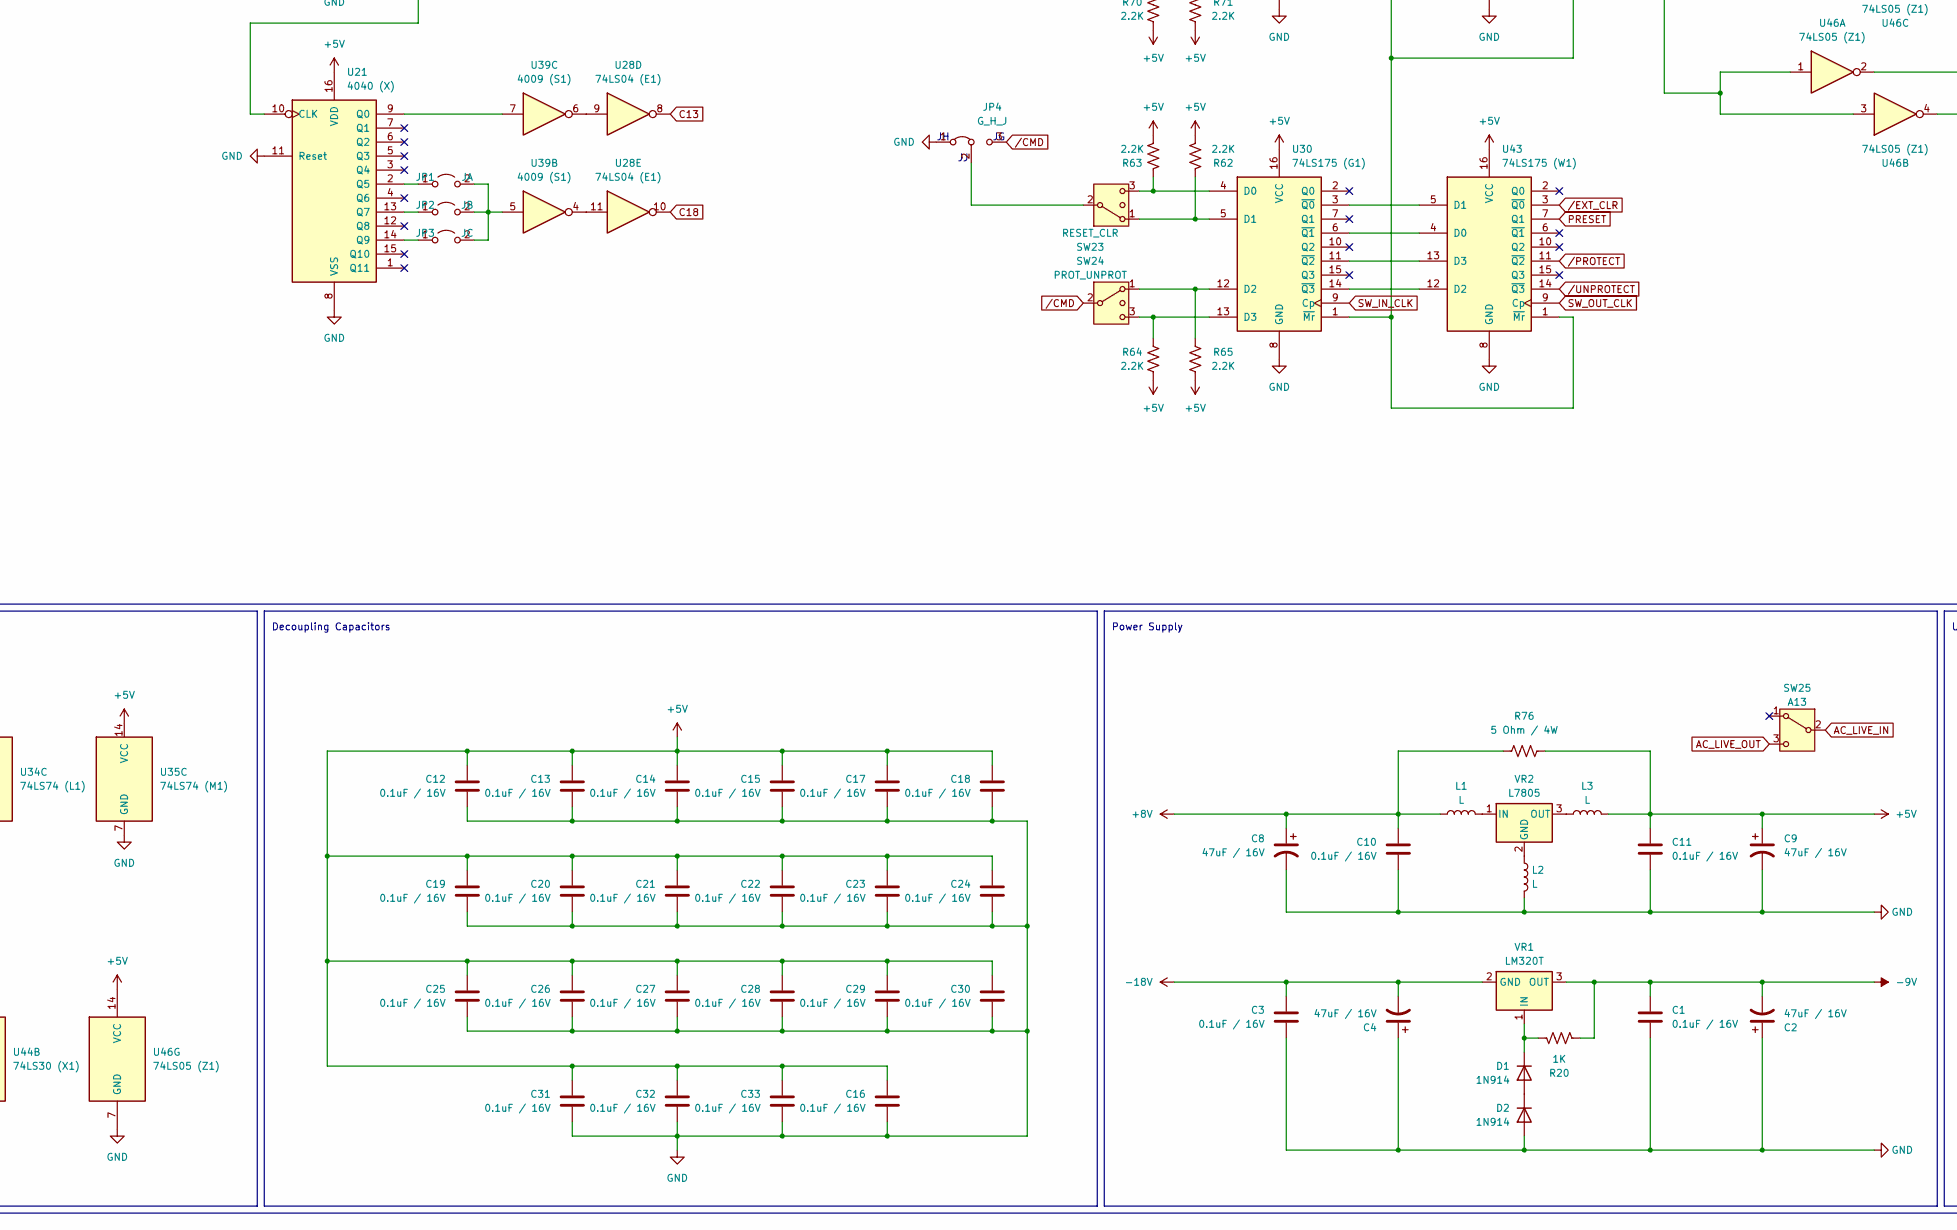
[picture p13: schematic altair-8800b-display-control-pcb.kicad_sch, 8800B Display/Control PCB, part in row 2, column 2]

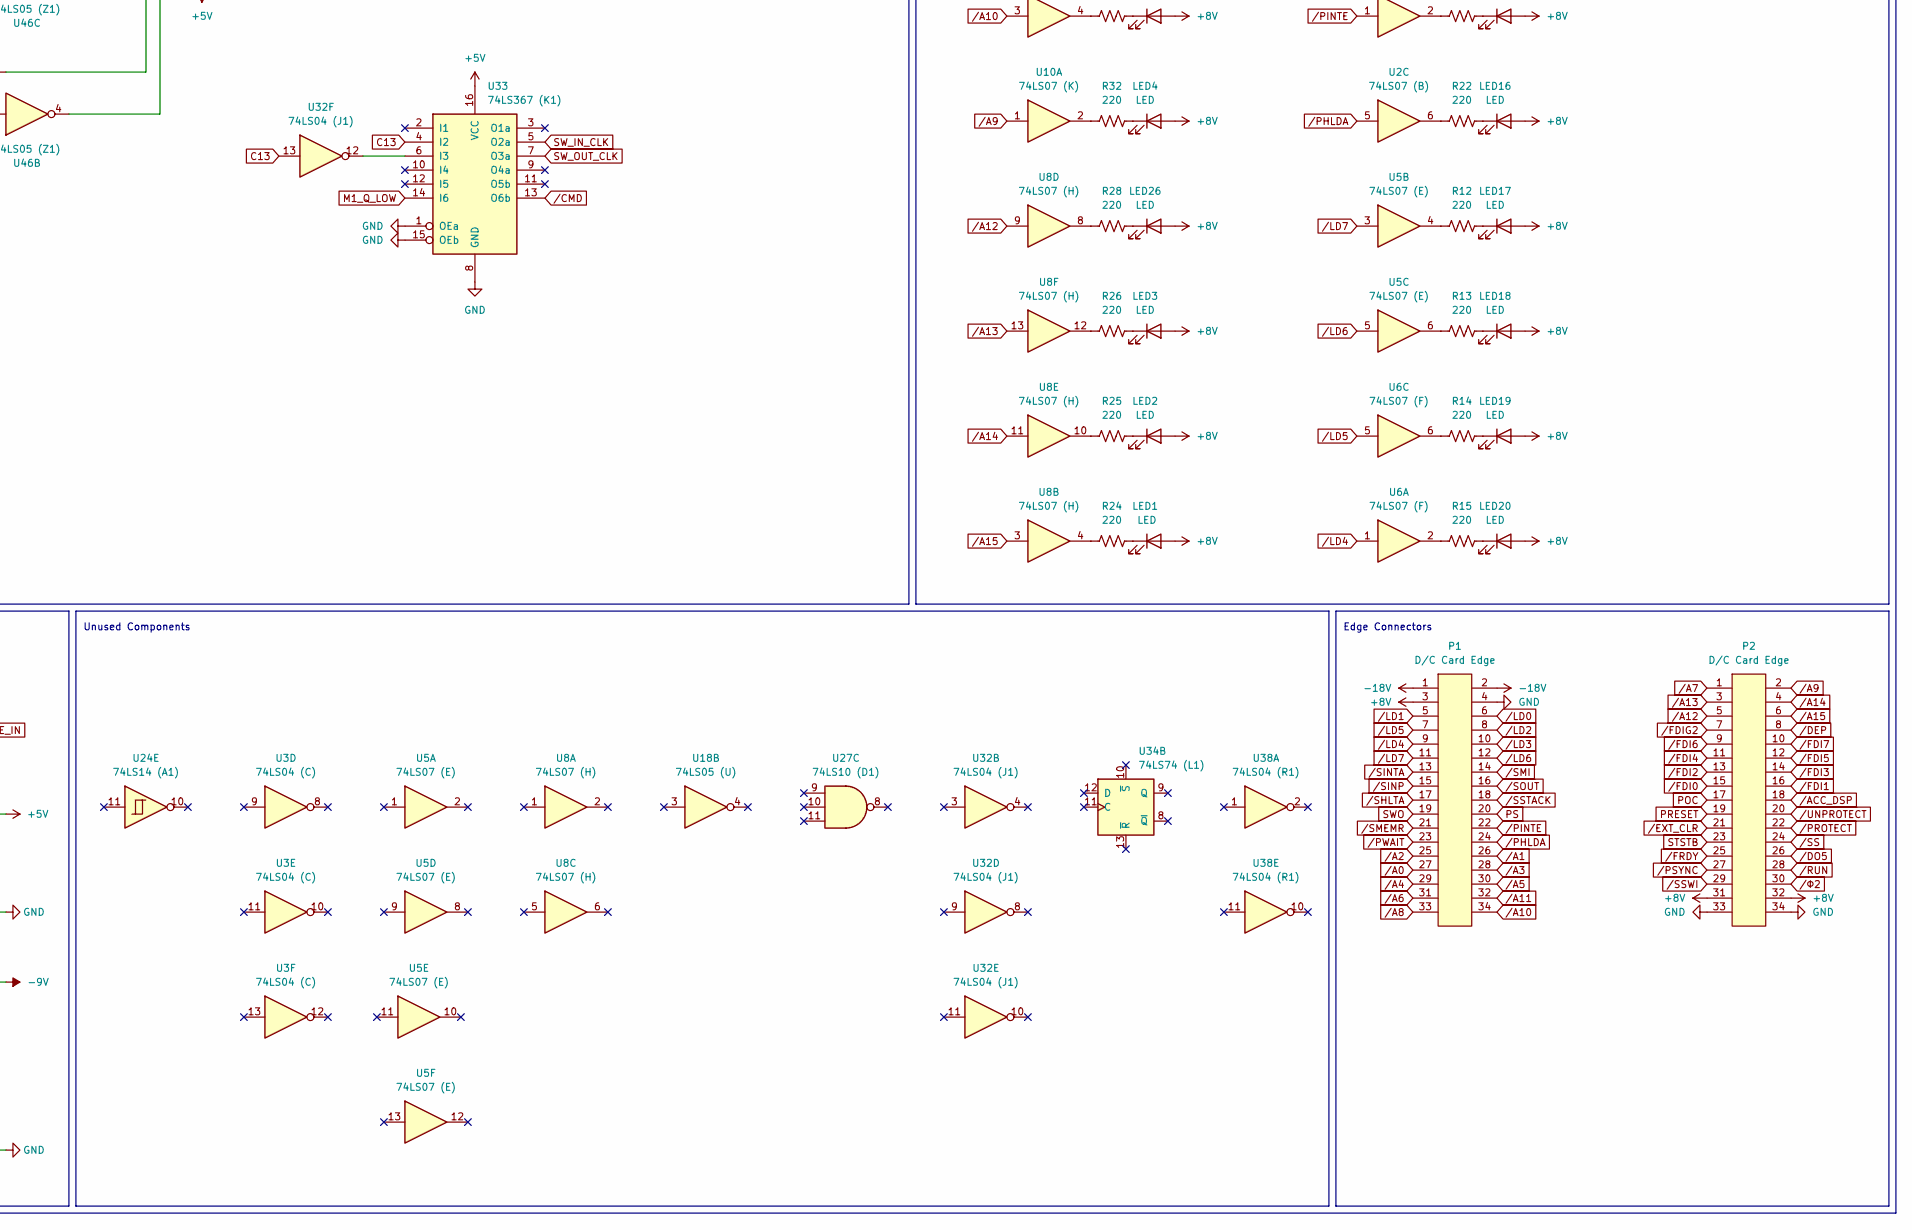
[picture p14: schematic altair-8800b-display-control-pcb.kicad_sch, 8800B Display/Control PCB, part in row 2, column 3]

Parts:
C1, C3, C10, C11, C12, C13, C14, C15, C16, C17, C18, C19, C20, C21, C22, C23, C24, C25, C26, C27, C28, C29, C30, C31, C32, C33: 0.1uF / 16V; C_Disc_D7.0mm_W2.3mm_P5.00mm
C2, C4, C8, C9: 47uF / 16V; CP_Radial_Tantal_D4.5mm_P2.50mm
C5, C6, C7: 0.001uF; C_Disc_D7.0mm_W2.3mm_P5.00mm
D1, D2: 1N914; D_DO-35_SOD27_P7.62mm_Horizontal
J1: JF_JE; PinHeader_1x02_P2.54mm_Vertical
JP1: JA; PinHeader_1x02_P2.54mm_Vertical
JP2: JB; PinHeader_1x02_P2.54mm_Vertical
JP3: JC; PinHeader_1x02_P2.54mm_Vertical
JP4: G_H_J; PinHeader_1x03_P2.54mm_Vertical
L1, L2, L3: L; L_Axial_L5.3mm_D2.2mm_P7.62mm_Horizontal_Vishay_IM-1
LED1, LED2, LED3, LED4, LED5, LED6, LED7, LED8, LED9, LED10, LED11, LED12, LED13, LED14, LED15, LED16, LED17, LED18, LED19, LED20, LED21, LED22, LED23, LED24, LED25, LED26, LED27, LED28, LED29, LED30, LED31, LED32, LED33, LED34, LED35, LED36: LED; LED_D5.0mm
P1, P2: D/C Card Edge; Altair_8800B_Display_Control_Card_Edge
R1, R23, R27, R31, R42, R43, R44, R45, R46, R47, R48, R49, R51, R52, R53, R54, R55, R56, R57, R58, R59, R60, R61, R62, R63, R64, R65, R67, R68, R69, R70, R71, R72, R74: 2.2K; R_Axial_DIN0309_L9.0mm_D3.2mm_P12.70mm_Horizontal
R2, R3, R4, R5, R6, R7, R8, R9, R10, R11, R12, R13, R14, R15, R16, R17, R18, R19, R21, R22, R24, R25, R26, R28, R29, R30, R32, R33, R34, R35, R36, R37, R38, R39, R40, R41, R73: 220; R_Axial_DIN0309_L9.0mm_D3.2mm_P12.70mm_Horizontal
R20: 1K; R_Axial_DIN0309_L9.0mm_D3.2mm_P12.70mm_Horizontal
R50, R75: 100; R_Axial_DIN0309_L9.0mm_D3.2mm_P12.70mm_Horizontal
R66: 470; R_Axial_DIN0309_L9.0mm_D3.2mm_P12.70mm_Horizontal
R76: 5 Ohm / 4W; R_Axial_DIN0516_L15.5mm_D5.0mm_P30.48mm_Horizontal
RP1: 4.7K; R_Array_SIP6
SW1: A0; Altair_Toggle_Switch
SW2: A1; Altair_Toggle_Switch
SW3: A2; Altair_Toggle_Switch
SW4: A3; Altair_Toggle_Switch
SW5: A4; Altair_Toggle_Switch
SW6: A5; Altair_Toggle_Switch
SW7: A6; Altair_Toggle_Switch
SW8: A7; Altair_Toggle_Switch
SW9: A8; Altair_Toggle_Switch
SW10: A9; Altair_Toggle_Switch
SW11: A10; Altair_Toggle_Switch
SW12: A11; Altair_Toggle_Switch
SW13: A12; Altair_Toggle_Switch
SW14, SW25: A13; Altair_Toggle_Switch
SW15: A14; Altair_Toggle_Switch
SW16: A15; Altair_Toggle_Switch
SW17: STOP_RUN; Altair_Toggle_Switch_Momentary
SW18: STEP_SLOW; Altair_Toggle_Switch_Momentary
SW19: EXAMINE_NEXT; Altair_Toggle_Switch_Momentary
SW20: DEPOSIT_NEXT; Altair_Toggle_Switch_Momentary
SW21: ACC_DIS_DEP; Altair_Toggle_Switch_Momentary
SW22: IN_OUT; Altair_Toggle_Switch_Momentary
SW23: RESET_CLR; Altair_Toggle_Switch_Momentary
SW24: PROT_UNPROT; Altair_Toggle_Switch_Momentary
U1: 8212 (A); DIP-24_W15.24mm_LongPads
U2: 74LS07 (B); DIP-14_W7.62mm_LongPads
U3: 74LS04 (C); DIP-14_W7.62mm_LongPads
U4: 74LS07 (D); DIP-14_W7.62mm_LongPads
U5: 74LS07 (E); DIP-14_W7.62mm_LongPads
U6: 74LS07 (F); DIP-14_W7.62mm_LongPads
U8: 74LS07 (H); DIP-14_W7.62mm_LongPads
U9: 74LS10 (J); DIP-14_W7.62mm_LongPads
U10: 74LS07 (K); DIP-14_W7.62mm_LongPads
U11: 4040 (L); DIP-16_W7.62mm_LongPads
U12: 74LS07 (M); DIP-14_W7.62mm_LongPads
U13: 74LS30 (N); DIP-14_W7.62mm_LongPads
U14: 7493 (P); DIP-14_W7.62mm_LongPads
U15: 74LS368 (R); DIP-16_W7.62mm_LongPads
U16: 74LS368 (S); DIP-16_W7.62mm_LongPads
U17: 8212 (T); DIP-24_W15.24mm_LongPads
U18: 74LS05 (U); DIP-14_W7.62mm_LongPads
U19: 74LS10 (V); DIP-14_W7.62mm_LongPads
U20: 74LS05 (W); DIP-14_W7.62mm_LongPads
U21: 4040 (X); DIP-16_W7.62mm_LongPads
U22: 74LS05 (Y); DIP-14_W7.62mm_LongPads
U23: 74LS00 (Z); DIP-14_W7.62mm_LongPads
U24: 74LS14 (A1); DIP-14_W7.62mm_LongPads
U25: 8212 (B1); DIP-24_W15.24mm_LongPads
U26: 74LS175 (C1); DIP-16_W7.62mm_LongPads
U27: 74LS10 (D1); DIP-14_W7.62mm_LongPads
U28: 74LS04 (E1); DIP-14_W7.62mm_LongPads
U29: 74LS175 (F1); DIP-16_W7.62mm_LongPads
U30: 74LS175 (G1); DIP-16_W7.62mm_LongPads
U31: 74LS175 (H1); DIP-16_W7.62mm_LongPads
U32: 74LS04 (J1); DIP-14_W7.62mm_LongPads
U33: 74LS367 (K1); DIP-16_W7.62mm_LongPads
U34: 74LS74 (L1); DIP-14_W7.62mm_LongPads
U35: 74LS74 (M1); DIP-14_W7.62mm_LongPads
U36: 74LS175 (N1); DIP-16_W7.62mm_LongPads
U37: 74LS00 (P1); DIP-14_W7.62mm_LongPads
U38: 74LS04 (R1); DIP-14_W7.62mm_LongPads
U39: 4009 (S1); DIP-16_W7.62mm_LongPads
U40: 74LS10 (T1); DIP-14_W7.62mm_LongPads
U41: 74LS175 (U1); DIP-16_W7.62mm_LongPads
U42: 74LS05 (V1); DIP-14_W7.62mm_LongPads
U43: 74LS175 (W1); DIP-16_W7.62mm_LongPads
U44: 74LS30 (X1); DIP-14_W7.62mm_LongPads
U45: 74LS175 (Y1); DIP-16_W7.62mm_LongPads
U46: 74LS05 (Z1); DIP-14_W7.62mm_LongPads
UA7: 1702 (G); DIP-24_W15.24mm_LongPads
UB7: 2732 (G)
VR1: LM320T; TO-220-3_Horizontal_TabDown
VR2: L7805; TO-220-3_Horizontal_TabDown

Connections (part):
+5V: C9.1, C11.1, C12.1, C13.1, C14.1, C15.1, C16.1, C17.1, C18.1, C19.1, C20.1, C21.1, C22.1, C23.1, C24.1, C25.1, C26.1, C27.1, C28.1, C29.1, C30.1, C31.1, C32.1, C33.1, L3.2, R1.1, R23.1, R27.1, R31.1, R42.1, R43.1, R44.1, R45.2, R46.2, R47.2, R48.2, R49.1, R51.2, R52.1, R53.2, R54.1, R55.2, R56.1, R57.2, R58.1, R59.2, R60.1, R61.2, R62.2, R63.1, R64.1, R65.2, R66.1, R67.2, R68.2, R69.1, R70.1, R71.2, R72.2, R74.1, R76.2, RP1.1 (R1), U1.24 (VCC), U2.14 (VCC), U3.14 (VCC), U4.14 (VCC), U5.14 (VCC), U6.14 (VCC), U8.14 (VCC), U9.14 (VCC), U10.14 (VCC), U11.16 (VDD), U12.14 (VCC), U13.14 (VCC), U14.5 (VCC), U15.16 (VCC), U16.16 (VCC), U17.24 (VCC), U18.14 (VCC), U19.14 (VCC), U20.14 (VCC), U21.16 (VDD), U22.14 (VCC)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
+8V: C8.1, C10.1, L1.1, LED1.2 (A), LED2.2 (A), LED3.2 (A), LED4.2 (A), LED5.2 (A), LED6.2 (A), LED7.2 (A), LED8.2 (A), LED9.2 (A), LED10.2 (A), LED11.2 (A), LED12.2 (A), LED13.2 (A), LED14.2 (A), LED15.2 (A), LED16.2 (A), LED17.2 (A), LED18.2 (A), LED19.2 (A), LED20.2 (A), LED21.2 (A), LED22.2 (A), LED23.2 (A), LED24.2 (A), LED25.2 (A), LED26.2 (A), LED27.2 (A), LED28.2 (A), LED29.2 (A), LED30.2 (A), LED31.2 (A), LED32.2 (A), LED33.2 (A), LED34.2 (A), LED35.2 (A), LED36.2 (A), P1.3, P2.31, P2.32, R76.1
-9V: C1.1, C2.2, R20.2, UA7.16 (VGG), UA7.24 (VDD), VR1.3 (OUT)
-18V: C3.1, C4.2, P1.1, P1.2, VR1.2 (GND)
/RA0: U1.1 (/DS1), U9.1, U9.5, U9.10, U14.1 (CKB), U14.12 (QA), U23.2, UA7.3 (A0), UB7.8 (A0)
/RA1: U14.9 (QB), UA7.2 (A1), UB7.7 (A1)
/RA2: U14.8 (QC), UA7.1 (A2), UB7.6 (A2)
/RA3: U14.11 (QD), UA7.21 (A3), UB7.5 (A3)
/RDO0: U1.3 (DI1), U13.2, U15.14 (I6), UA7.4 (D0), UB7.9 (D0)
/RDO1: U1.5 (DI2), U13.3, U15.12 (I5), UA7.5 (D1), UB7.10 (D1)
/RDO2: U1.7 (DI3), U13.12, U15.10 (I4), UA7.6 (D2), UB7.11 (D2)
/RDO3: U1.9 (DI4), U13.4, U16.2 (I1), UA7.7 (D3), UB7.13 (D3)
/RDO4: U1.16 (DI5), U13.11, U16.4 (I2), UA7.8 (D4), UB7.14 (D4)
/RDO5: U1.18 (DI6), U13.5, U15.6 (I3), UA7.9 (D5), UB7.15 (D5)
/RDO6: U1.20 (DI7), U13.6, U15.4 (I2), UA7.10 (D6), UB7.16 (D6)
/RDO7: U1.22 (DI8), U15.2 (I1), U24.1, UA7.11 (D7), UB7.17 (D7)
AC_LIVE_IN: SW25.2 (B)
AC_LIVE_OUT: SW25.3 (C)
AL_STB: U17.11 (STB), U25.11 (STB), U34.5 (Q)
C8: U23.5, U28.2
C13: U28.8, U32.13, U33.4 (I2)
C18: U28.10, U37.10
CS: U1.13 (DS2), U9.2, U9.4, U28.6
GND: C1.2, C2.1, C3.2, C4.1, C5.1, C6.1, C7.1, C8.2, C9.2, C10.2, C11.2, C12.2, C13.2, C14.2, C15.2, C16.2, C17.2, C18.2, C19.2, C20.2, C21.2, C22.2, C23.2, C24.2, C25.2, C26.2, C27.2, C28.2, C29.2, C30.2, C31.2, C32.2, C33.2, D2.2 (A), JP4.1 (A), L2.2, P1.4, P2.33, P2.34, SW17.2 (3), U1.12 (GND), U2.7 (GND), U3.7 (GND), U4.7 (GND), U5.7 (GND), U6.7 (GND), U8.7 (GND), U9.7 (GND), U10.7 (GND), U11.8 (VSS), U11.11 (Reset), U12.7 (GND), U13.7 (GND), U14.10 (GND), U15.8 (GND), U16.8 (GND), U17.1 (/DS1), U17.2 (MD), U17.12 (GND), U18.7 (GND), U19.7 (GND), U20.7 (GND), U21.8 (VSS), U21.11 (Reset), U22.7 (GND), U23.7 (GND), U24.7 (GND), U25.1 (/DS1), U25.2 (MD), U25.12 (GND), U26.8 (GND), U27.7 (GND), U28.7 (GND), U29.8 (GND), U30.8 (GND), U31.8 (GND), U32.7 (GND), U33.1 (OEa), U33.8 (GND), U33.15 (OEb), U34.7 (GND), U35.7 (GND), U36.8 (GND)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
M1_Q_LOW: U33.14 (I6), U35.6 (~Q), U37.5
unnamed: C5.2, R73.2, U32.5
unnamed: C6.2, R50.2, U24.5
unnamed: D1.2 (A), D2.1 (K)
unnamed: D1.1 (K), R20.1, VR1.1 (IN)
unnamed: J1.1, U27.3, U38.6
unnamed: J1.2, R51.1, U40.1
unnamed: JP1.1 (A), U21.2 (Q5)
unnamed: JP1.2 (B), JP2.2 (B), JP3.2 (B), U39.5
unnamed: JP2.1 (A), U21.13 (Q7)
unnamed: JP3.1 (A), U21.14 (Q9)
unnamed: JP4.2 (C), SW23.2 (3)
unnamed: LED1.1 (K), R24.2
unnamed: LED2.1 (K), R25.2
unnamed: LED3.1 (K), R26.2
unnamed: LED4.1 (K), R32.2
unnamed: LED5.1 (K), R33.2
unnamed: LED6.1 (K), R34.2
unnamed: LED7.1 (K), R40.2
unnamed: LED8.1 (K), R38.2
unnamed: LED9.1 (K), R39.2
unnamed: LED10.1 (K), R9.2
unnamed: LED11.1 (K), R8.2
unnamed: LED12.1 (K), R7.2
unnamed: LED13.1 (K), R21.2
unnamed: LED14.1 (K), R10.2
unnamed: LED15.1 (K), R3.2
unnamed: LED16.1 (K), R22.2
unnamed: LED17.1 (K), R12.2
unnamed: LED18.1 (K), R13.2
unnamed: LED19.1 (K), R14.2
unnamed: LED20.1 (K), R15.2
unnamed: LED21.1 (K), R16.2
unnamed: LED22.1 (K), R17.2
unnamed: LED23.1 (K), R18.2
unnamed: LED24.1 (K), R19.2
unnamed: LED25.1 (K), R29.2
unnamed: LED26.1 (K), R28.2
unnamed: LED27.1 (K), R30.2
unnamed: LED28.1 (K), R35.2
unnamed: LED29.1 (K), R36.2
unnamed: LED30.1 (K), R37.2
unnamed: LED31.1 (K), R11.2
unnamed: LED32.1 (K), R41.2
unnamed: LED33.1 (K), R2.2
unnamed: LED34.1 (K), R6.2
unnamed: LED35.1 (K), R5.2
unnamed: LED36.1 (K), R4.2
unnamed: R2.1, U2.12
unnamed: R3.1, U2.2
unnamed: R4.1, U2.8
unnamed: R5.1, U4.8
unnamed: R6.1, U4.10
unnamed: R7.1, U4.6
unnamed: R8.1, U4.4
unnamed: R9.1, U4.2
unnamed: R10.1, U2.10
unnamed: R11.1, U4.12
unnamed: R12.1, U5.4
unnamed: R13.1, U5.6
unnamed: R14.1, U6.6
unnamed: R15.1, U6.2
unnamed: R16.1, U6.4
unnamed: R17.1, U6.8
unnamed: R18.1, U6.10
unnamed: R19.1, U6.12
unnamed: R21.1, U2.4
unnamed: R22.1, U2.6
unnamed: R24.1, U8.4
unnamed: R25.1, U8.10
unnamed: R26.1, U8.12
unnamed: R27.2, U19.5
unnamed: R28.1, U8.8
unnamed: R29.1, U10.6
unnamed: R30.1, U10.4
unnamed: R31.2, U9.9
unnamed: R32.1, U10.2
unnamed: R33.1, U10.10
unnamed: R34.1, U10.12
unnamed: R35.1, U10.8
unnamed: R36.1, U12.6
unnamed: R37.1, U12.4
unnamed: R38.1, U12.2
unnamed: R39.1, U12.10
unnamed: R40.1, U12.12
unnamed: R41.1, U12.8
unnamed: R50.1, U23.6
unnamed: R67.1, U44.1, U44.2, U44.11, U44.12
unnamed: C7.2, R75.1, RP1.2 (R1.2), U39.3
unnamed: SW1.2 (B), U22.12
unnamed: SW2.2 (B), U22.8
unnamed: SW3.2 (B), U22.10
unnamed: SW4.2 (B), U22.6
unnamed: SW5.2 (B), U22.4
unnamed: SW6.2 (B), U22.2
unnamed: SW7.2 (B), U20.12
unnamed: SW8.2 (B), U20.8
unnamed: SW9.2 (B), U20.10
unnamed: SW10.2 (B), U20.6
unnamed: SW11.2 (B), U20.4
unnamed: SW12.2 (B), U20.2
unnamed: SW13.2 (B), U18.12
unnamed: SW14.2 (B), U18.10
unnamed: SW15.2 (B), U18.8
unnamed: SW16.2 (B), U18.2
unnamed: R54.2, SW17.3 (4), U26.4 (D0)
unnamed: R57.1, SW18.3 (4), U26.13 (D3)
unnamed: R58.2, SW19.3 (4), U29.4 (D0)
unnamed: R60.2, SW20.3 (4), U29.13 (D3)
unnamed: R69.2, SW21.3 (4), U31.4 (D0)
unnamed: R70.2, SW22.3 (4), U31.13 (D3)
unnamed: R63.2, SW23.3 (4), U30.4 (D0)
unnamed: R64.2, SW24.3 (4), U30.13 (D3)
unnamed: R1.2, U1.2 (MD), U1.11 (STB), U1.14 (/CLR)
unnamed: U2.11, U3.2
unnamed: U2.13, U3.4
unnamed: U11.10 (CLK), U39.2
unnamed: U11.2 (Q5), U39.9
unnamed: U11.4 (Q6), U39.11
unnamed: U11.13 (Q7), U39.14
unnamed: U11.1 (Q11), U21.10 (CLK)
unnamed: U13.1, U24.2
unnamed: U13.8, U24.3
unnamed: U14.2 (RO1), U23.11
unnamed: R49.2, U14.3 (RO2)
unnamed: U15.1 (OEa), U15.15 (OEb), U16.1 (OEa), U16.15 (OEb), U24.8
unnamed: R74.2, U17.14 (/CLR), U25.14 (/CLR)
unnamed: U18.1, U18.5, U18.9, U18.11, U18.13, U20.1, U20.3, U20.5, U20.11, U23.8
unnamed: U19.1, U28.1, U39.15
unnamed: U19.2, U28.4
unnamed: U9.6, U19.3
unnamed: U3.6, U19.4
unnamed: U19.6, U19.9, U19.10, U19.11
unnamed: U19.12, U28.5
unnamed: U19.13, U28.12
unnamed: U21.9 (Q0), U39.7
unnamed: U23.1, U24.4
unnamed: U23.3, U23.4
unnamed: U23.9, U24.12
unnamed: R55.1, SW17.1, U26.5 (D1)
unnamed: R56.2, SW18.1, U26.12 (D2)
unnamed: R66.2, U26.1 (~Mr), U29.1 (~Mr), U30.1 (~Mr), U31.1 (~Mr), U36.1 (~Mr), U41.1 (~Mr), U43.1 (~Mr), U45.1 (~Mr)
unnamed: U26.3 (~Q0), U36.5 (D1)
unnamed: U26.6 (~Q1), U36.4 (D0)
unnamed: U26.11 (~Q2), U36.13 (D3)
unnamed: U26.14 (~Q3), U36.12 (D2)
unnamed: U27.2, U37.8
unnamed: U27.4, U38.4, U40.2, U40.11
unnamed: U27.6, U37.4
unnamed: U28.3, U39.12
unnamed: U28.9, U39.6
unnamed: U28.11, U39.4
unnamed: R59.1, SW19.1, U29.5 (D1)
unnamed: R61.1, SW20.1, U29.12 (D2)
unnamed: U29.3 (~Q0), U41.5 (D1)
unnamed: U29.6 (~Q1), U41.4 (D0)
unnamed: U29.11 (~Q2), U41.13 (D3)
unnamed: U29.14 (~Q3), U41.12 (D2)
unnamed: R62.1, SW23.1, U30.5 (D1)
unnamed: R65.1, SW24.1, U30.12 (D2)
unnamed: U30.3 (~Q0), U43.5 (D1)
unnamed: U30.6 (~Q1), U43.4 (D0)
unnamed: U30.11 (~Q2), U43.13 (D3)
unnamed: U30.14 (~Q3), U43.12 (D2)
unnamed: R68.1, SW21.1, U31.5 (D1)
unnamed: R71.1, SW22.1, U31.12 (D2)
unnamed: U31.3 (~Q0), U45.5 (D1)
unnamed: U31.6 (~Q1), U45.4 (D0)
unnamed: U31.11 (~Q2), U45.13 (D3)
unnamed: U31.14 (~Q3), U45.12 (D2)
unnamed: U32.1, U40.6
unnamed: U32.12, U33.6 (I3)
unnamed: U34.3 (C), U44.8
unnamed: R72.1, U34.2 (D), U34.4 (~S)
unnamed: U35.3 (C), U37.6
unnamed: U35.2 (D), U36.7 (Q1)
unnamed: U35.1 (~R), U37.3
unnamed: U27.12, U35.11 (C)
unnamed: R53.1, U35.10 (~S), U35.12 (D)
unnamed: U32.2, U35.13 (~R)
unnamed: U36.2 (Q0), U37.1
unnamed: U36.15 (Q3), U37.9
unnamed: U27.1, U36.11 (~Q2)
unnamed: U37.11, U38.13
unnamed: U38.8, U40.9
unnamed: U40.4, U40.8
unnamed: U40.3, U40.12
unnamed: U41.2 (Q0), U42.1
unnamed: U41.7 (Q1), U42.5
unnamed: U41.10 (Q2), U42.13
unnamed: U41.15 (Q3), U42.3
unnamed: U45.2 (Q0), U46.11, U46.13
unnamed: U42.9, U42.11, U45.7 (Q1)
unnamed: U45.10 (Q2), U46.5, U46.9
unnamed: U45.15 (Q3), U46.1, U46.3
unnamed: L2.1, VR2.2 (GND)
unnamed: L1.2, VR2.1 (IN)
unnamed: L3.1, VR2.3 (OUT)
POC: P2.17, R73.1
PRESET: P2.19, U43.7 (Q1)
PS: P1.20, U3.3
P_CKA: U14.14 (CKA), U24.6
RA4: RP1.3 (R2.2), U42.4, U44.3, U46.4, U46.6, UA7.20 (A4), UB7.4 (A4)
RA5: RP1.4 (R3.2), U42.12, U44.4, U46.8, U46.10, UA7.19 (A5), UB7.3 (A5)
RA6: RP1.5 (R4.2), U42.2, U42.10, U44.5, U46.2, U46.12, UA7.18 (A6), UB7.2 (A6)
RA7: RP1.6 (R5.2), U42.6, U42.8, U44.6, UA7.17 (A7), UB7.1 (A7)
S1: U1.21 (DO8), U20.9, U20.13, U22.1, U22.3, U22.5, U22.9, U22.11, U22.13
S2: U1.19 (DO7), U24.13
S3: U1.17 (DO6), U25.13 (DS2)
S4: U1.15 (DO5), U17.13 (DS2)
S5: U1.10 (DO4), U24.9
S6: U1.8 (DO3), U3.5, U9.11
S7: U1.6 (DO2), U9.3
S8: U1.4 (DO1), U9.13
STSTB: P2.23, U27.5, U40.10, U40.13
SWO: P1.19, U3.1
SW_IN_CLK: U26.9 (Cp), U29.9 (Cp), U30.9 (Cp), U31.9 (Cp), U33.5 (O2a)
SW_OUT_CLK: U33.7 (O3a), U36.9 (Cp), U41.9 (Cp), U43.9 (Cp), U45.9 (Cp)
/A0: P1.27, U12.9, U25.22 (DI8)
/A1: P1.26, U12.11, U25.20 (DI7)
/A2: P1.25, U12.13, U25.18 (DI6)
/A3: P1.28, U12.1, U25.16 (DI5)
/A4: P1.29, U12.3, U25.9 (DI4)
/A5: P1.30, U12.5, U25.7 (DI3)
/A6: P1.31, U10.9, U25.5 (DI2)
/A7: P2.1, U10.13, U25.3 (DI1)
/A8: P1.33, U10.11, U17.22 (DI8)
/A9: P2.2, U10.1, U17.20 (DI7)
/A10: P1.34, U10.3, U17.18 (DI6)
/A11: P1.32, U10.5, U17.16 (DI5)
/A12: P2.5, U8.9, U17.9 (DI4)
/A13: P2.3, U8.13, U17.7 (DI3)
/A14: P2.4, U8.11, U17.5 (DI2)
/A15: P2.6, U8.3, U17.3 (DI1)
/ACC_DSP: P2.18, U45.6 (~Q1)
/C6: U28.13, U34.1 (~R), U39.10
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

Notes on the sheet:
Power Distribution
Power Supply
Unused Components
Edge Connectors
Display/Control Logic
Decoupling Capacitors

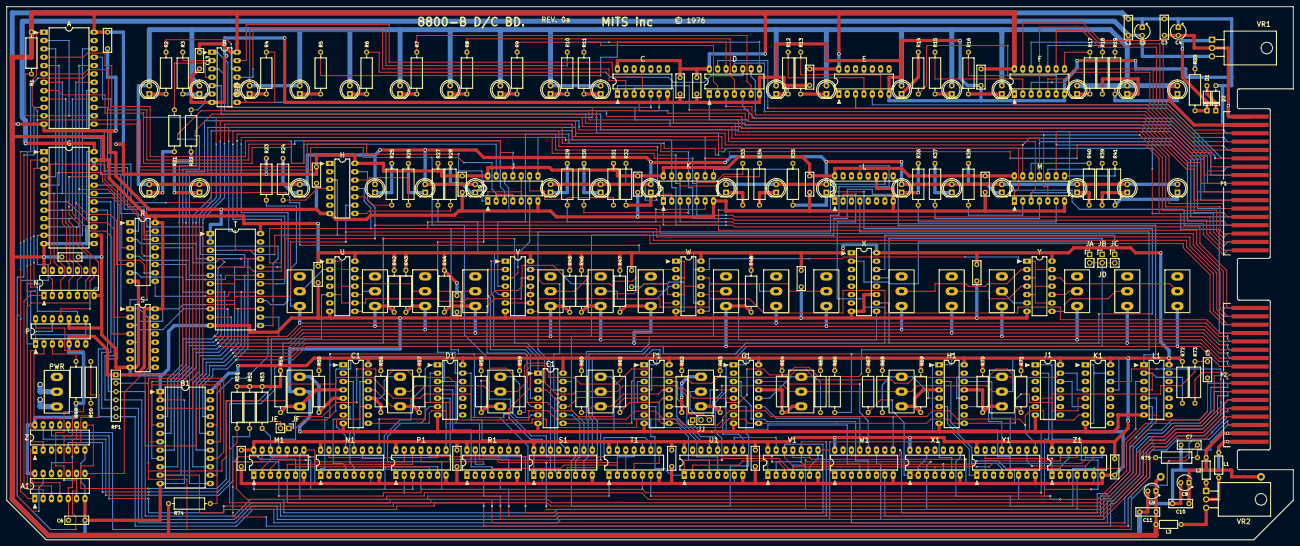
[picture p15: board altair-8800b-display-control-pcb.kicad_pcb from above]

Board: 2 copper layers, 391.0 x 162.0 mm, 231 parts (1 on the bottom side), 300 nets.

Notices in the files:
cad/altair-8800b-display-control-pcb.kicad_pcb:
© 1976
